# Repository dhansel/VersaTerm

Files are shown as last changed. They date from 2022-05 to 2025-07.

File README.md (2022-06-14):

# VersaTerm
A versatile DIY serial terminal.

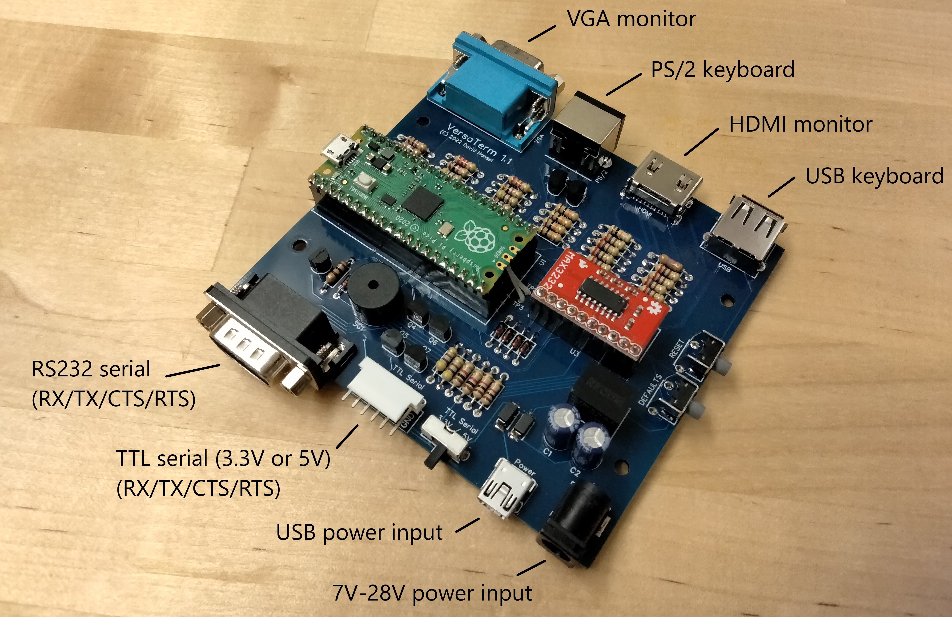
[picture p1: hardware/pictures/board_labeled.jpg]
Labeled Board

(more pictures [here](hardware/pictures/ReadMe.md))

## Highlights

- Instant-on/Instant-off - no waiting for OS to boot, no need to shut down safely
- Native HDMI and VGA video output (no conversion)
- Supports PS/2 and USB keyboards (including keyboards with integrated USB hubs)
- RS232 and TTL level serial input/output (TTL switchable between 3.3V and 5V)
- Wide range of baud rates: 50-921600 baud (presets and custom)
- Supports hardware (RTS/CTS) and software (XOn/XOff) flow control
- Can be powered via USB or 7-28V DC
- [Highly configurable](software/screenshots/settings.md), including user-uploadable fonts (bitmaps)
- Supports all [VT100 attributes](software/screenshots/vt100.md): bold/underline/blink/inverse/double width/double height
- Supports [16 ANSI colors](software/screenshots/vt100.md#ANSI-colors)
- Decent VT100 control sequence support - [passes VTTest tests](software/screenshots/vttest.md) for 80-column VT52/VT100/VT102
- [PETSCII mode](software/screenshots/petscii.md) supports PETSCII character set and control characters, PETSCII (C64) font included
- Easy to DIY - vast majority of soldering is through-hole, firmware can be uploaded via USB (no special equipment required)

### Limitations

The terminal is powered by a Raspberry Pi Pico. The Pico is a microcontroller and does not have integrated graphics
capabilities. It can however still produce video signals (see [PicoDVI](https://github.com/Wren6991/PicoDVI) 
and [PicoVGA](https://github.com/Panda381/PicoVGA)). 
Some limitations for the terminal arise from the Pico's limited processing power:

- Max 80 columns per row (no 132 column support)
- Font characters must be 8 pixels wide (original VT100 was 10 pixels), height can be 8-16 pixels
- 16 Ansi colors only (no 8-bit or 24-bit color support)
- No smooth scrolling (emulated via delayed scrolling)

## Building VersaTerm

This is not a kit but building VersaTerm should be fairly easy:

- The Gerber file to produce the PCB is available [here](https://github.com/dhansel/VersaTerm/raw/main/hardware/PCB/VersaTermGerber.zip)
- See [here](hardware/PCB/ReadMe.md) for component sourcing and assembly tips
- STL files for 3d printing an enclosure can be found [here](hardware/enclosure)
- Instructions on how to upload the firmware binary (via USB micro cable, no extra hardware needed) are [here](software/ReadMe.md)

## Using VersaTerm

### Settings menu and multiple configurations.

The settings menu can be entered by pressing the F12 keyboard key and navigated
using the cursor keys.

The "Manage Configurations" sub-menu provides 10 slots to save configurations
(e.g. if you want to use VersTerm with different computers).
- To save the current settings to the selected cofiguration slot, press "S"
- To make the selected configuration slot the startup default, press "*"
- To give the selected configuration slot a name, press "N"

You can switch between configurations via either of these methods:
- On startup or RESET, hold down the F1-F10 keyboard keys to select a configuration
- While VersaTerm is on, press CTRL and F1-F10 to load a configuration
- Press CTRL+F12 to open a quick-select menu that shows your configurations and their names

### Video output selection (HDMI/VGA)

VersaTerm can produce either VGA or HDMI output but not both at the same time. On startup, VersaTerm detects whether
a HDMI monitor is connected (via the HDMI "Hot Plug Detect" signal pin). If a HDMI monitor is detected then HDMI
output is produced, otherwise VGA. You can disable auto-detect and directly specify the output type in the "Screen"
settings menu. If your HDMI monitor is not detected at all, the HDMI output can be forced by doing the following:

- Connect a keyboard
- Hold down the RESET and DEFAULTS buttons on the side of the VersaTerm PCB
- Hold down the CTRL key on the keyboard
- Release RESET

Doing so will use default settings but disable auto-detect and instead force HDMI output. 
Once you have a monitor image you can enter settings,  fix the output type to HDMI and save 
the settings so HDMI is always used automatically.

### USB mode

The Raspberry Pi Pico has only one USB port which can function either as a USB host or device.
If the Pico is connected to another computer using the USB micro socket on the Pico board then
VersaTerm will detect that at startup and run the USB port as a device. Otherwise it assumes
that the USB port should be run as a host and allow a USB keyboard to be connected.

Do not connect the Pico to another computer **and** plug in a USB keyboard at the same time. 
Doing so won't break anything but the USB port won't function properly.

If the USB port is plugged into another computer (i.e. used as a device) then VersaTerm should
be recognized by the computer as a USB CDC (serial) device. In that case there are three operating
modes that can be selected in the USB settings menu:
- *Serial.* In this mode VersaTerm views the USB connection as a secondary serial connection. Any data received is treated just the same as data received on the main serial connection and keypresses are sent to both the main and the USB connection.
- *Feed-through.* In this mode (which is the default) VersaTerm forwards any data received on the main serial connection to USB and vice versa. This way VersaTerm can be used as a USB-to-serial converter.
- *Feed-through (terminal disabled).* Similar to the basic feed-through mode but VersaTerm won't process any input it receives from the main serial connection. This can be used to transfer (binary) data between the main serial connection and the USB serial connection without messing up the terminal display.

### Resetting the terminal

The terminal can be reset by pressing the RESET button on the side of the PCB. 

If you get yourself into a situation where VersaTerm will not work because of invalid default settings
(e.g. set to force HDMI output but you only have a VGA monitor), hold down the DEFAULTS button
(next to RESET) on the side of the PCB while pressing and releasing RESET. This will re-start
VersaTerm with the default settings.

## Screen Shots

See [here](software/screenshots/ReadMe.md) for some demonstrations of VersaTerm's capabilities

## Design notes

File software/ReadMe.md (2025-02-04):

## Uploading the VersaTerm firmware to the Raspberry Pi Pico

Uploading firmware to the Raspberry Pi Pico is easy:
- Press and hold the button on the Raspberry Pi Pico (there is only one) 
- While holding the button, connect the Raspberry Pi Pico via its micro-USB port to your computer
- Release the button
- Your computer should recognize the Pico as a storage device (like a USB stick) and mount it as a drive
- Copy the [VersaTerm.uf2](software/VersaTerm.uf2) file to the drive mounted in the previous step

## Building the VersaTerm firmware from source

### Requirements
- CMake 3.12 or later
- GCC (cross-)compiler: arm-none-eabi-gcc

### Getting and building the source

```
git clone https://github.com/dhansel/VersaTerm.git
cd VersaTerm/software/lib
git submodule update --init
cd pico-sdk/lib
git submodule update --init
cd tinyusb
git checkout 86ad6e5
cd ../../../..
mkdir build
cd build
cmake .. -DPICO_SDK_PATH=../lib/pico-sdk -DPICO_COPY_TO_RAM=1
make
```

The `git checkout 86ad6e5` command updates TinyUSB to version 0.18 instead of version 0.12
which was included with the pico-sdk version used by VersaTerm. Version 0.12 has issues
with (some) USB hubs which are resolved in 0.18.

This should create file VersaTerm/software/build/src/VersaTerm.uf2<br>
Follow the "Uploading firmware to Raspberry Pi Pico" instructions above to upload the .uf2 file to the Pico.

The instructions above will use the of pico-sdk and PicoDVI versions that were
current when I wrote and tested VersaTerm. Building from those sources should result in
the same VerTerm.uf2 file as the one in VersaTerm/software.

If you feel adventurous you can build VersaTerm with the latest versions of the libraries:
```
git clone https://github.com/dhansel/VersaTerm.git
cd VersaTerm/software/lib
git submodule update --init
cd pico-sdk/lib
git submodule update --init
git submodule update --remote --merge
cd ../..
git submodule update --remote --merge
cd ..
mkdir build
cd build
cmake .. -DPICO_SDK_PATH=../lib/pico-sdk -DPICO_COPY_TO_RAM=1
make
```

## Some solutions to compile issues

A big thank you to user [unclouded](https://github.com/un-clouded) who reported a number of compile-time 
issues and their solutions:

When it said to me:

    arm-none-eabi-gcc: fatal error: cannot read spec file 'nosys.specs': No such file or directory

I replied:

    apt install libnewlib-arm-none-eabi

And when it said:

    fatal error: cassert: No such file or directory

I retorted:

    apt install libstdc++-arm-none-eabi-dev

And then it complained that:

    /usr/lib/gcc/arm-none-eabi/12.2.1/../../../arm-none-eabi/bin/ld: cannot find -lstdc++: No such file or directory

And I spake thusly:

    apt install libstdc++-arm-none-eabi-newlib

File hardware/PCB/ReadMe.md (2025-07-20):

# Component Ordering

I sourced most of the parts from DigiKey. The [VersaTermBOM.csv](VersaTermBOM.csv) file in this folder includes all the parts and their part numbers.
You can also click the link below to automatically create a shopping cart at DigiKey that contains most of the parts:<BR>
https://www.digikey.com/short/d0qw14h1

The the following necessary parts are currently not available at DigiKey and have to be ordered separately:
  - Raspberry Pi Pico: not sold at DigiKey, available at [AdaFruit](https://www.adafruit.com/product/4883), [SparkFun](https://www.sparkfun.com/products/17829), Ebay and others
  - 2N7000 MOSFET (need 7): currently (May 2022) on backorder at DigiKey. Available on EBay from various sellers.

If you want to use the provided [3d-printable enclosure](../enclosure), you will need four machine screws #4-40 with length 22mm (7/8") below the head and matching
#4-40 nuts. DigiKey part #335-1089-ND and #36-9600-ND will fit.
  
# Assembly tips
  
The vast majority of solder points are through-hole and easy to solder, except for the following:
  - Diodes D1 and D2 are surface-mount devices but the diodes themselves are fairly large. I have no SMD soldering experience and had no problem soldering them.
  - The Raspberry Pi Pico does not route the USB data signals to its pin headers. However, there are two test points (TP2 and TP3) on the bottom of the Pi Pico 
  on which the USB data signals can be accessed. Solder in a short wire from TP2 on the Pi Pico board to TP2 on the VersaTerm PCB. Same for TP3.
  <div align="center">
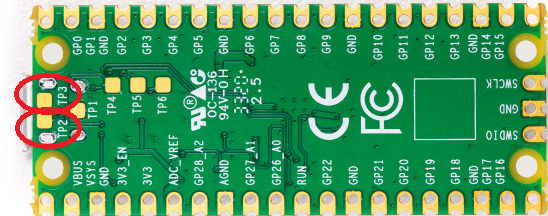
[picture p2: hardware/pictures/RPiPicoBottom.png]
  
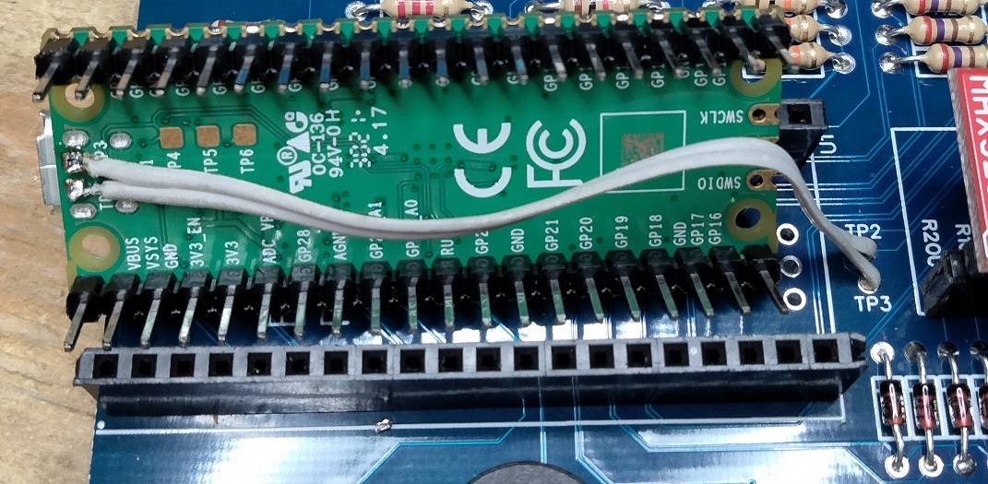
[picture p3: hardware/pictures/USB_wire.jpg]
  
  </div>
  
  - While the HDMI connector is through-hole, its pins are very closely spaced. I definitely recommend using a multimeter to check there are no solder bridges 
  between the pins after soldering.
  
  Other tips:
  - For the Raspberry Pi Pico, solder female header pins onto the PCB and then male header pins to the Pi Pico. That will make it easier to debug issues later 
  or to replace the Pico if that becomes necessary.
  - I also used male/female headers to connect the Max3232
  - When soldering the male Molex connector for the TTL serial connection to the board, do not stick it into the board as far as it will go, otherwise the 
  female connector will not fit afterwards. I recommend soldering the male connector while plugged into the female one, that way there is definitely enough space.

# Component Placement

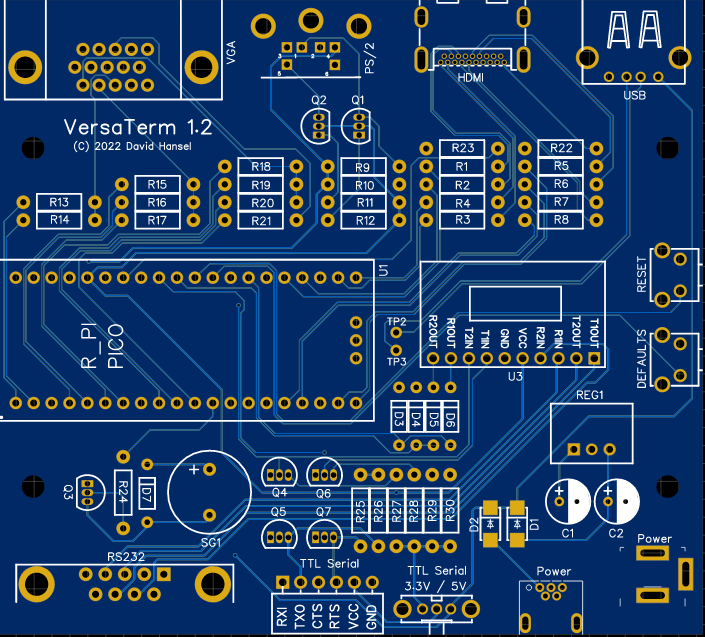
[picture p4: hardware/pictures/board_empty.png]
Empty Board

  
For supplier and manufacturer part numbers, see [VersaTermBOM.csv](VersaTermBOM.csv)

Designator	|  Component
------------|-------------
R21,R24	| Resistor 100 Ohm
R1,R2,R3,R4,R5,R6,R7,R8	| Resistor 270 Ohm
R14	| Resistor 390 Ohm
R17,R20,R25,R26	| Resistor 470 Ohm
R13,R16,R19,R27,R28	| Resistor 1k
R29,R30	| Resistor 1k or 10k (see note below)
R15,R18	| Resistor 2k2
R22	| Resistor 4.7k
R9,R10,R11,R12,R23	| Resistor 10k Ohm
D1,D2	| Diode SMT Schottky
D3,D4,D5,D6,D7 | Diode Axial 1N4148
Q1,Q2,Q3,Q4,Q5,Q6,Q7 | MOSFET 2N7000
C1,C2 | Capacitor 10uF
3.3V / 5V	| Switch
RESET,DEFAULTS | Button
REG1	| Recom 5V Regulator
SG1	| Buzzer
Power	| Barrel Connector
Power	| USB-B Mini Connector
VGA	| DB15 Connector
PS/2	| PS/2 Connector
HDMI	| HDMI Connector
USB	| USB-A Connector
RS232	| DB9 Connector
TTL Serial	| Molex Connector Male
U1	| Raspberry Pi Pico
U3	| MAX3232 board

**Note:** Some users have [reported](https://github.com/dhansel/VersaTerm/issues/16) issues with VersaTerm receiving data, which was caused by the R29/R30 1k pull-up resistors being too strong. 
If you experience issues receiving then I recommend switching these to 10k.

# Finished PCB
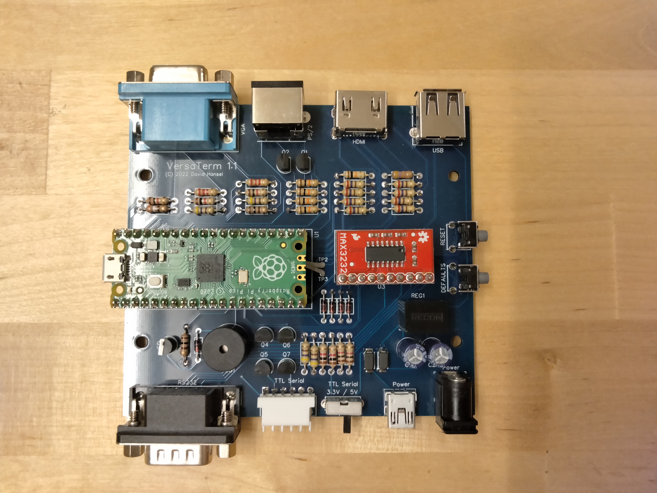
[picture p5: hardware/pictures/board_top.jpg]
board_top


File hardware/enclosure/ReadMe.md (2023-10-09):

The two halves of the encosure are held together using four machine screws #4-40 with 
length 22mm (7/8") below the head and matching #4-40 nuts. For example, DigiKey 
part #[335-1089-ND](https://www.digikey.com/en/products/detail/apm-hexseal/R4-40X7-8-2701/1159352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)
and #[36-9600-ND](https://www.digikey.com/en/products/detail/keystone-electronics/9600/2746248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) will fit.

If you would like to use M3 bolts instead, take a look at [this variation of the enclosure](DigicoolThings).

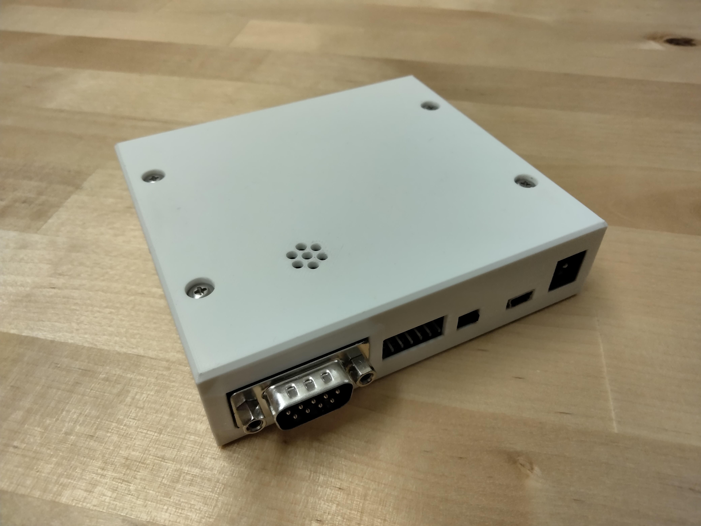
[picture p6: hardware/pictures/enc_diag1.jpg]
enclosure


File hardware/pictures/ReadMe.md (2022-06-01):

# PCB pictures

board_top
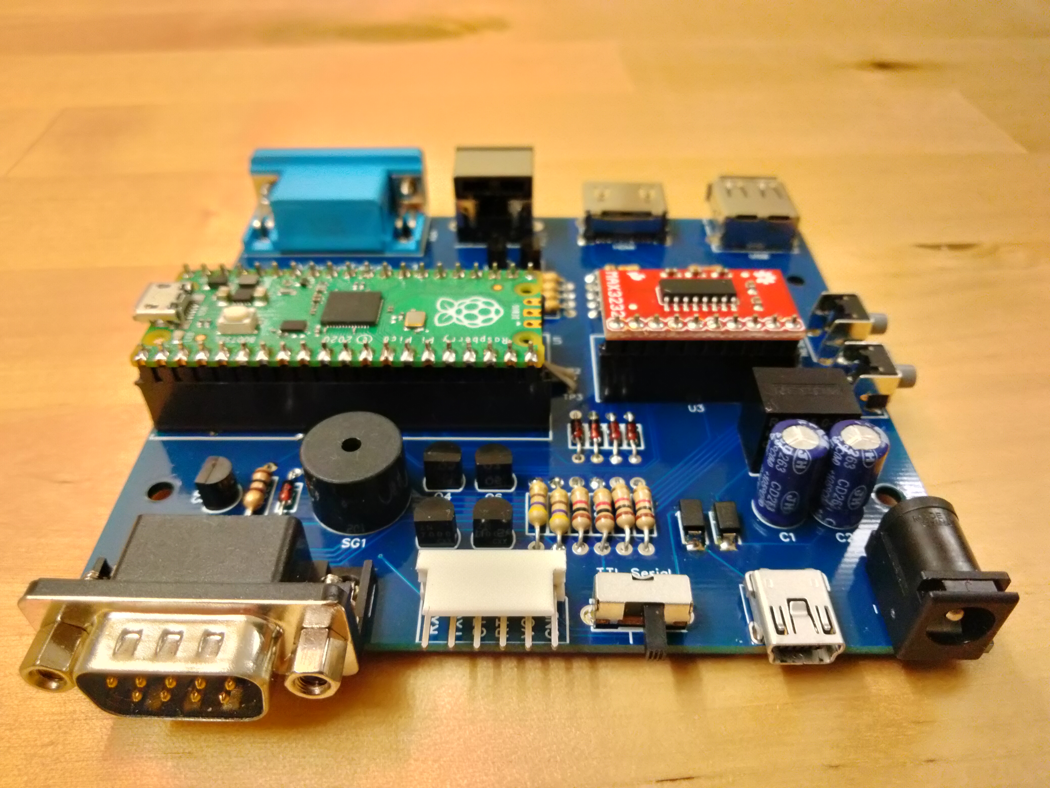
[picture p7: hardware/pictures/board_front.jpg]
board_front

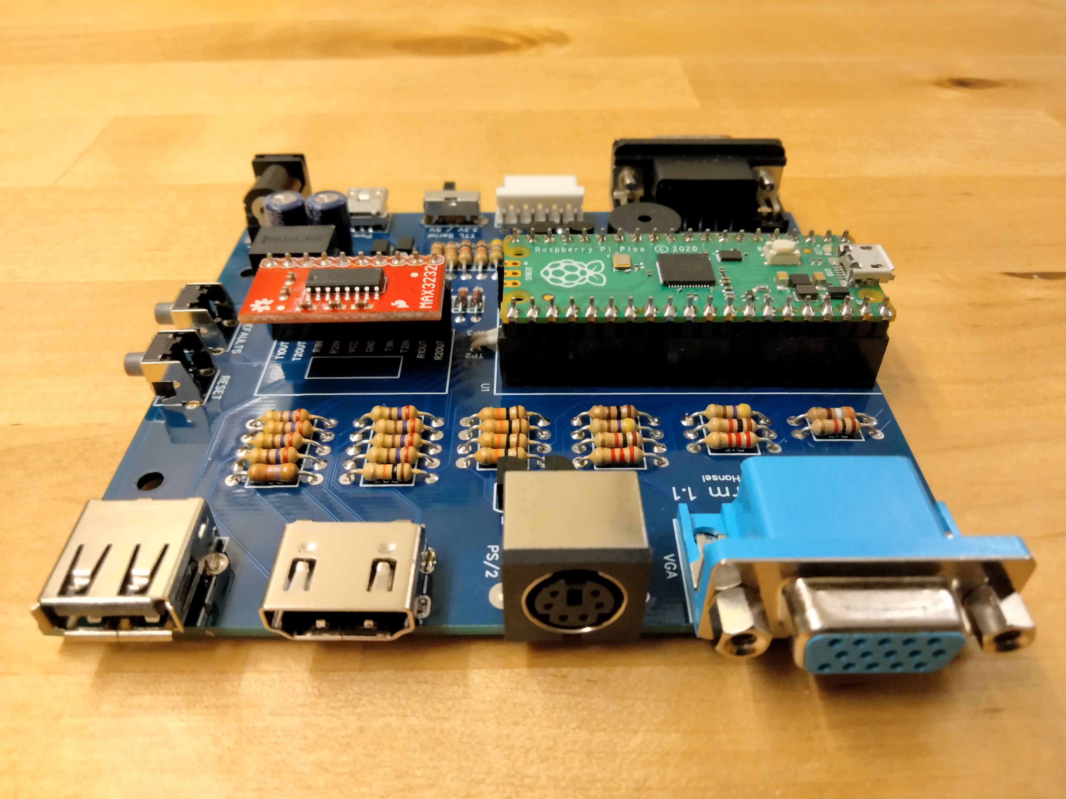
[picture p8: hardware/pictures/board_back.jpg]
board_back

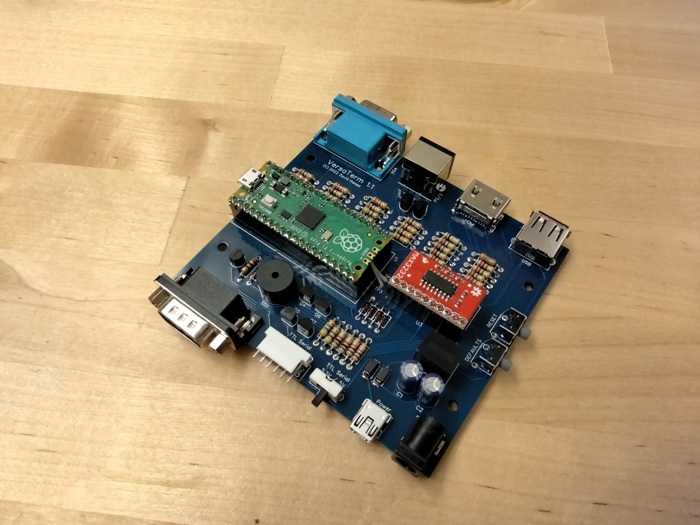
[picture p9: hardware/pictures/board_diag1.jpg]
board_diag1


# Enclosure pictures

enc_diag1
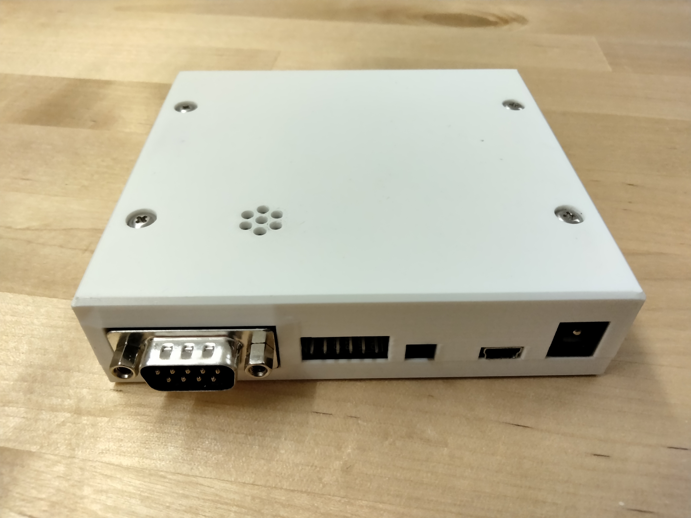
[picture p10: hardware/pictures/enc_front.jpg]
enc_front

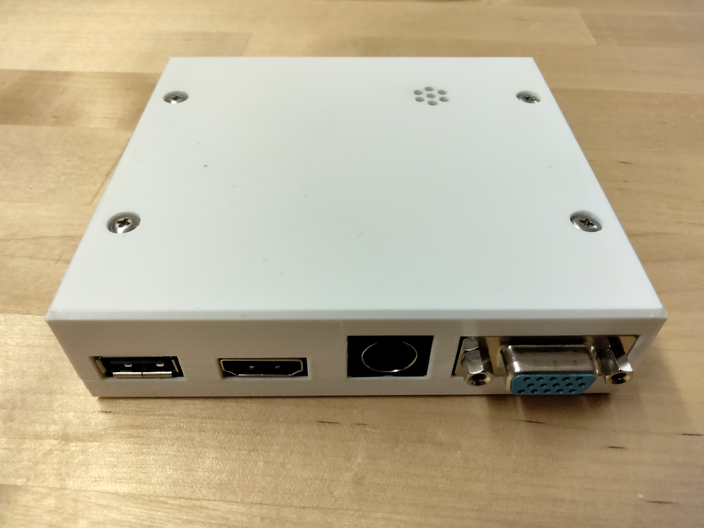
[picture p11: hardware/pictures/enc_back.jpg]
enc_back

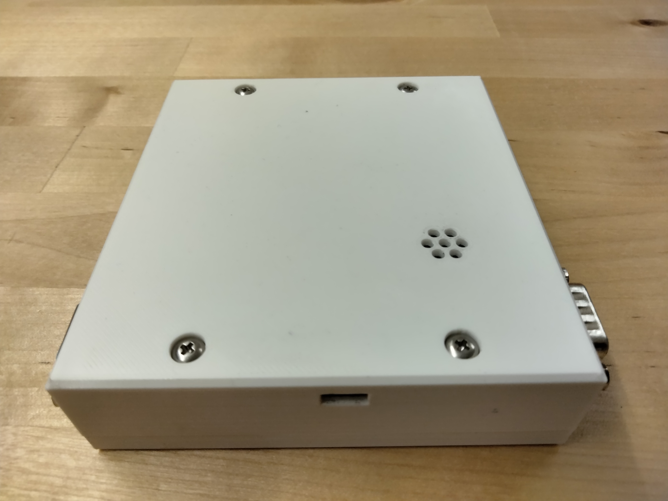
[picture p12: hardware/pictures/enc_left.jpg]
enc_left

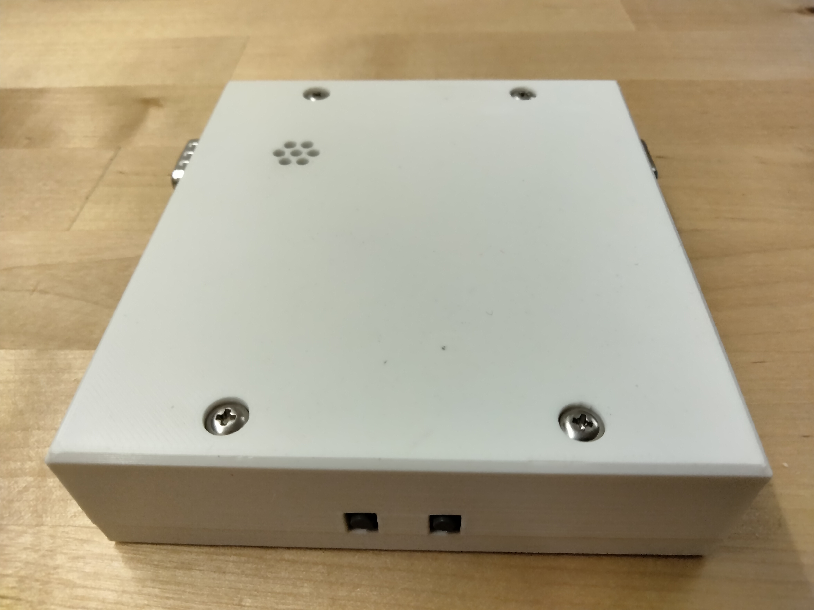
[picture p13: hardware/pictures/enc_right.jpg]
enc_right


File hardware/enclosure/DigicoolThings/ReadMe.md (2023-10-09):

This is a variation on my original enclosure, provided by Greg at [DigicoolThings](https://digicoolthings.com):

  - Bolt holes adjusted to take M3 Bolts (3.2mm), as more readily available to everyone in the metric world. 
  - Nut retainer holes adjusted for M3 Nuts (the imperial nut retainer holes were too big for M3 nuts).
  - Embeded Legends with the product name and the connector names added in 2 colors (for Bambu Lab AMS printing).

The 3d printer files for this version are available on MakerWorld:
https://makerworld.com/en/models/33128#profileId-29923

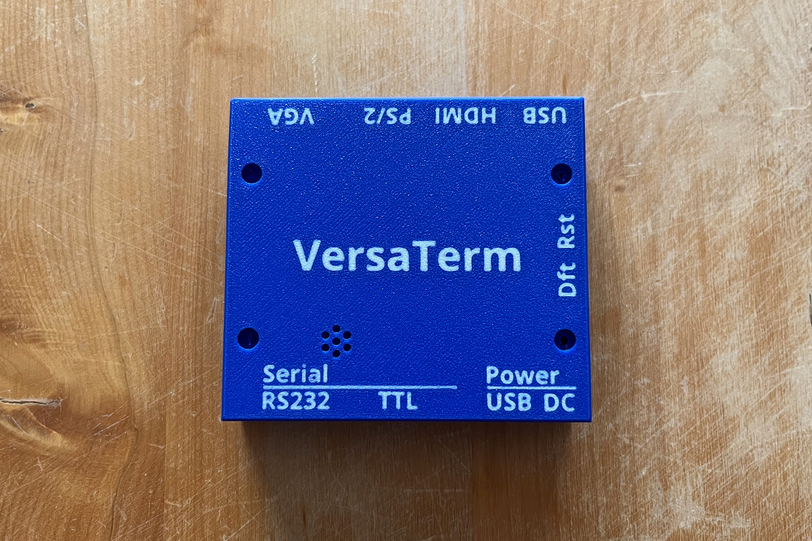
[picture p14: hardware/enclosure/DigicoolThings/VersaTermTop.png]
enclosure


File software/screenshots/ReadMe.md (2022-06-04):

# VT100/ASCII graphics

[Click here for more VT100 graphics screen shots](vt100.md)
<div align="center">
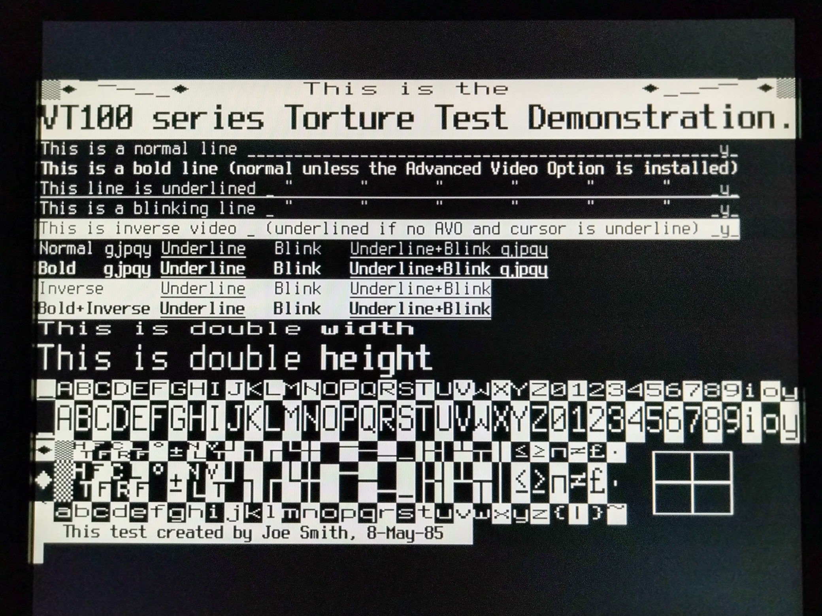
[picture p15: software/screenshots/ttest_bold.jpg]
More screenshots
  
</div>

# VTTest

[VTTest](https://invisible-island.net/vttest) is a test suite for VT100 compatibility.<br>
[Click here for more VTTest screen shots](vttest.md)
<div align="center">
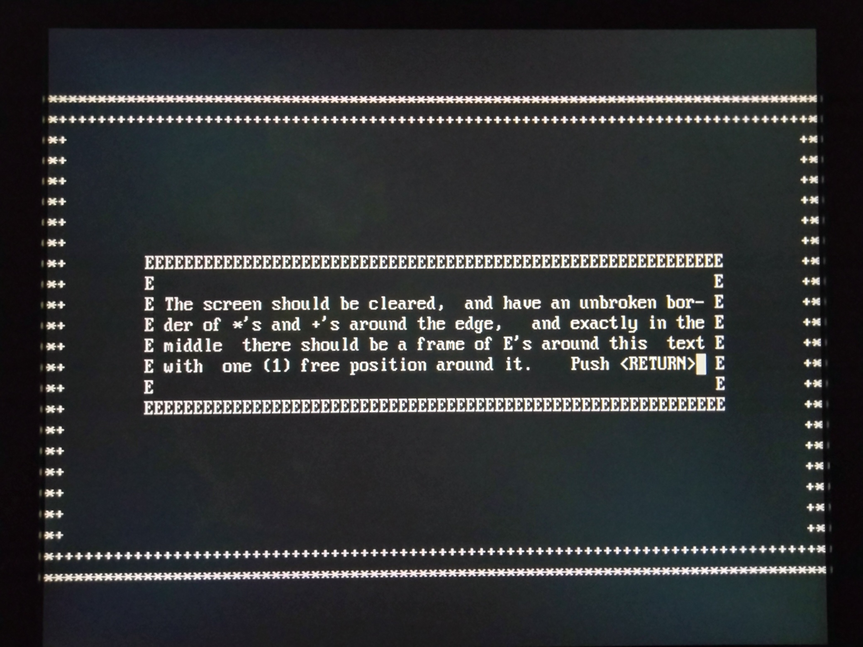
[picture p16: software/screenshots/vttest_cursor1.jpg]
More screenshots
  
</div>

# PETSCII graphics

[Click here for more PETSCII graphics screen shots](petscii.md)
<div align="center">
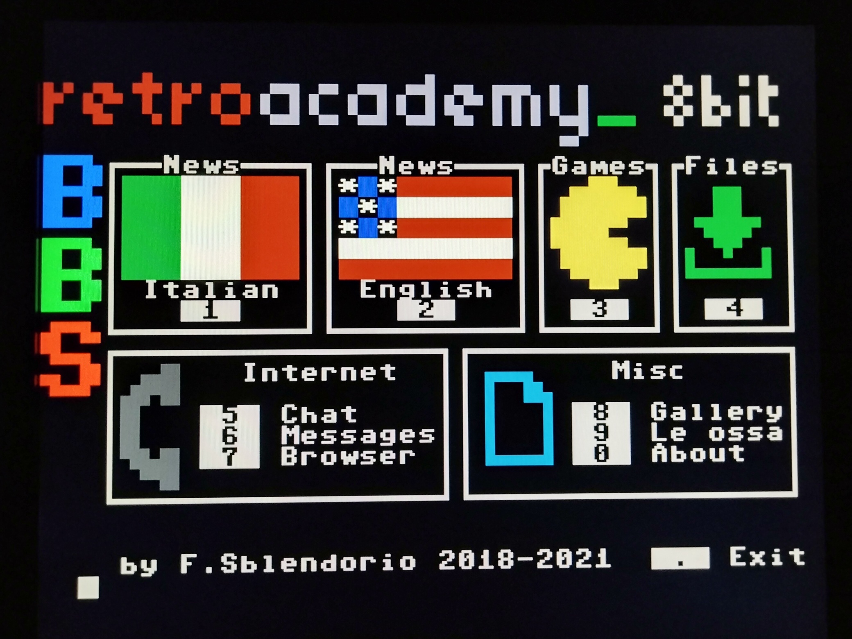
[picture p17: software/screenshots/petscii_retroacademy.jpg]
More screenshots
  
</div>

# Settings menu

[Click here for more settings screen shots](settings.md)
<div align="center">
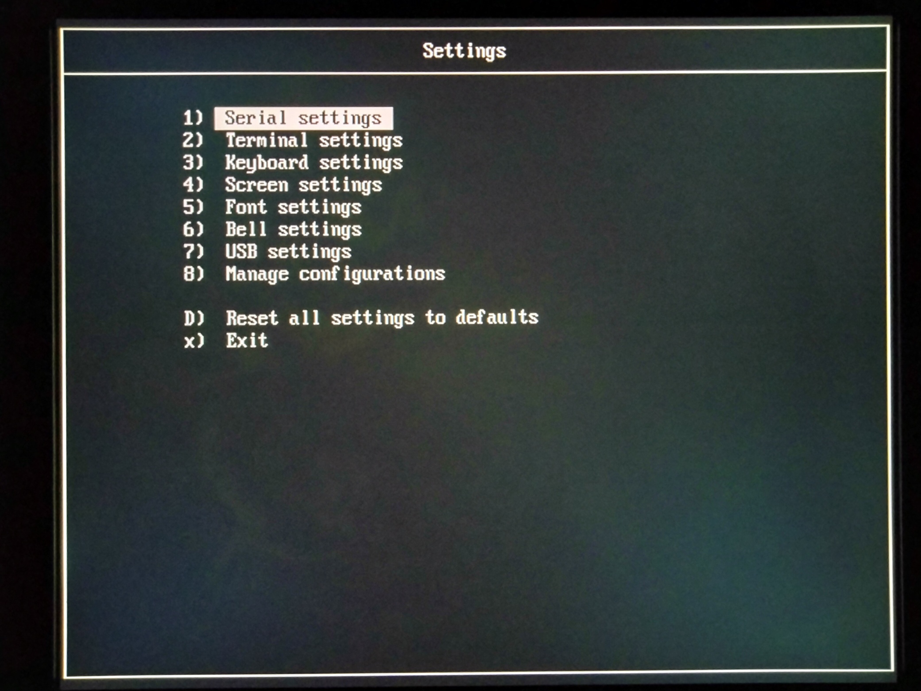
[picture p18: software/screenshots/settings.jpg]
More screenshots
  
</div>

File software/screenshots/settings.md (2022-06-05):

# Settings menu

settings
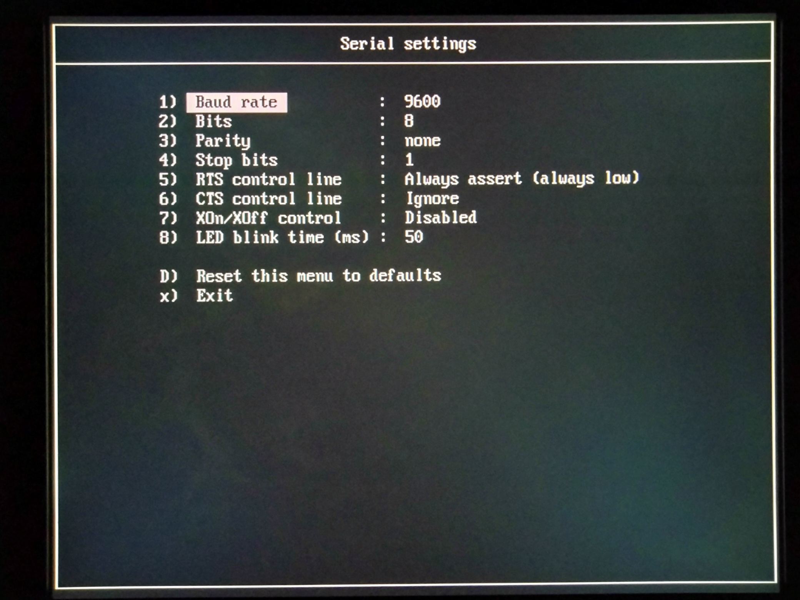
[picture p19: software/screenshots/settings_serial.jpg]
settings_serial

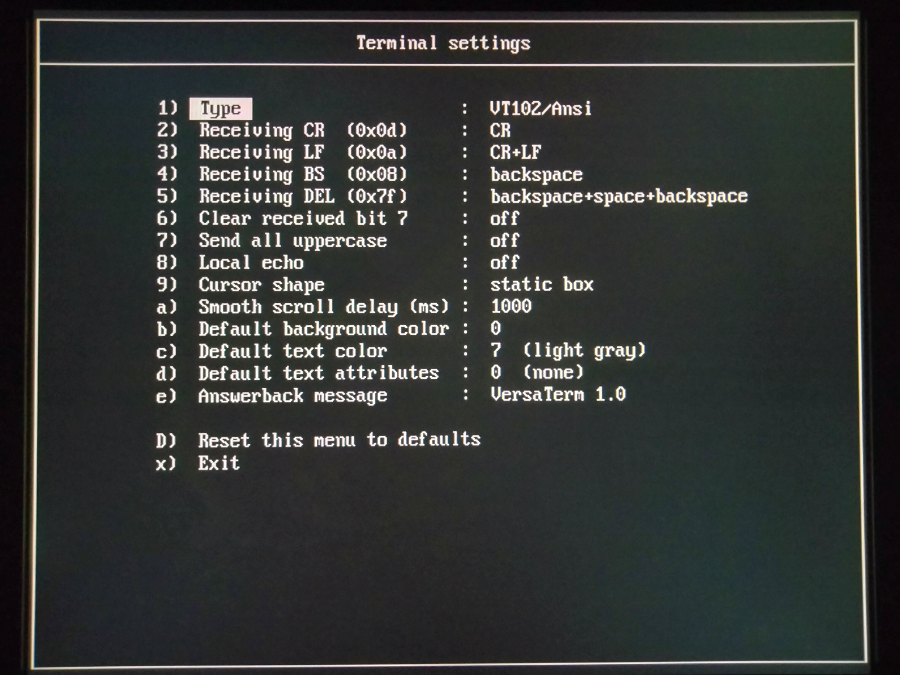
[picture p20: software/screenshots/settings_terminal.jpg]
settings_terminal

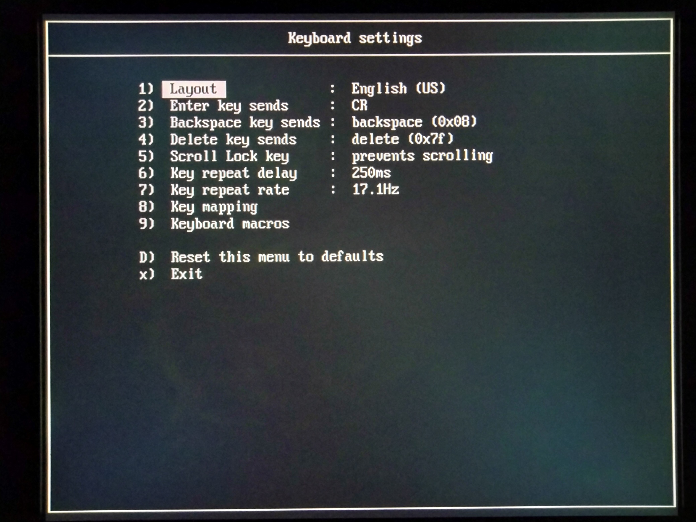
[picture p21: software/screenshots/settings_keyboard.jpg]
settings_keyboard

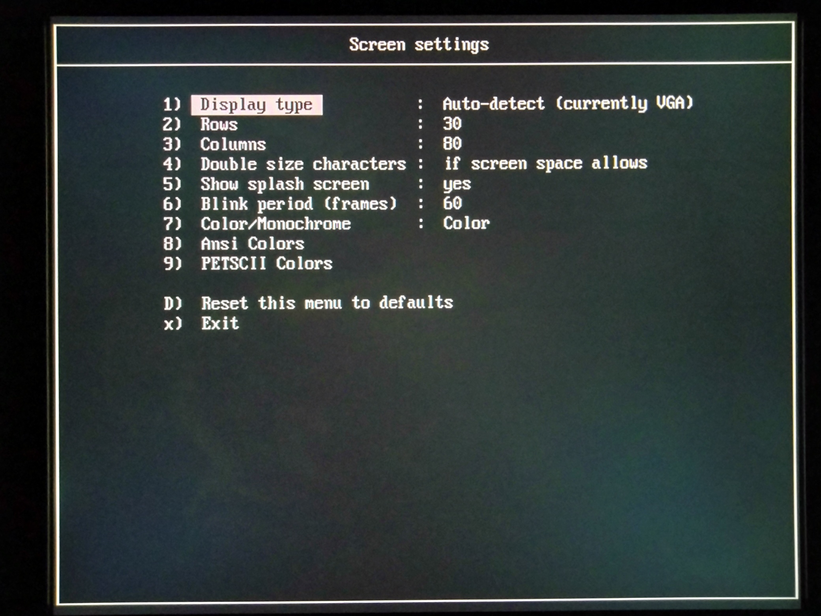
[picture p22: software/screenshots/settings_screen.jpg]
settings_screen

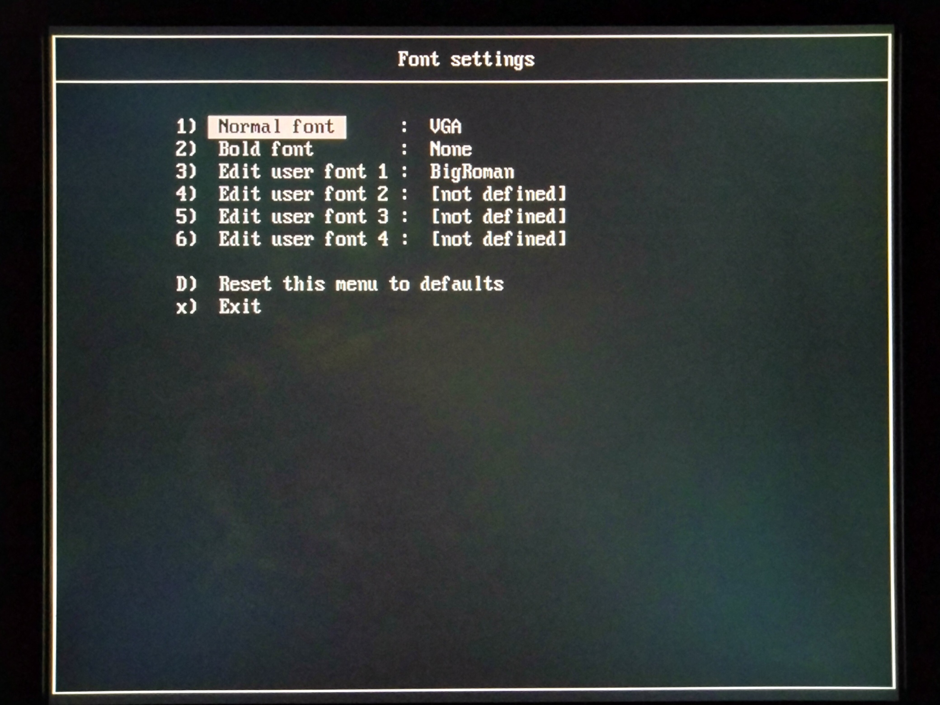
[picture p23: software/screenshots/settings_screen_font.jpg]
settings_screen_font

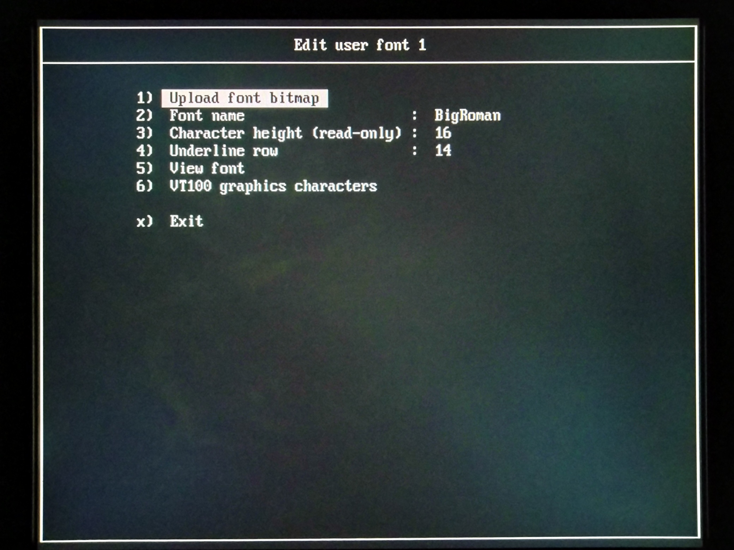
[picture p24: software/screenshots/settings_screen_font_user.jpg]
settings_screen_font_user

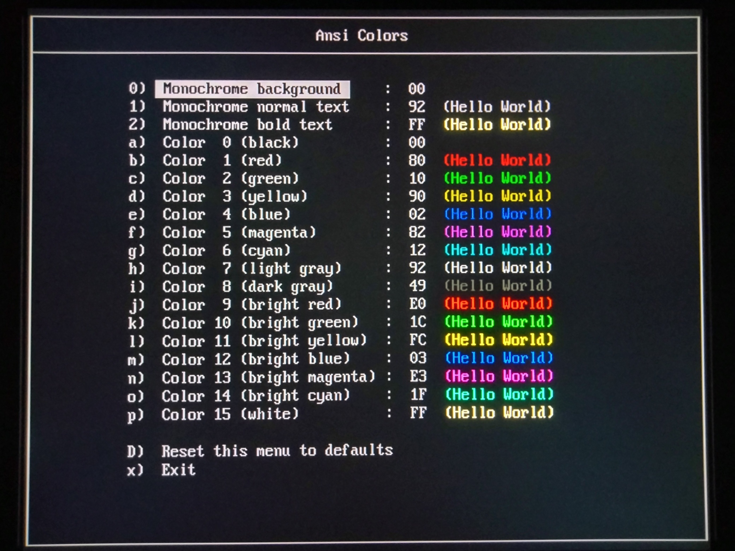
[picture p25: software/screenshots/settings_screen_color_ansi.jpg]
settings_screen_color_ansi

settings_screen_color_petscii
settings_bell
settings_usb
settings_configs

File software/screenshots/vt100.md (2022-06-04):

# VT100 / ASCII / ANSI graphics

### VT100 Torture test (using regular and bold font)

Source: http://artscene.textfiles.com/vt100 (torturet.vt)<br>
Font: Terminus / Terminus bold<br>
Click [here](https://youtu.be/B1N31KZlwjg) to see a video recording of this test.
<div align="center">
  <a href="https://youtu.be/B1N31KZlwjg">Watch the Video</a>
</div>

### VT100 Torture test (no bold font selected - using color instead)

Source: http://artscene.textfiles.com/vt100 (torturet.vt)<br>
Font: VGA / no bold font, using bright colors for bold characters<br>
Click [here](https://youtu.be/LtPrxeNTNgQ) to see a video recording of this test.
<div align="center">
  <a href="https://youtu.be/LtPrxeNTNgQ">Watch the Video</a>
</div>

### VT100 "Beer" animation

Source: http://artscene.textfiles.com/vt100 (newbeer.vt)<br>
Click [here](https://youtu.be/AVb2DMGUi1M) to see a video recording of this test.
<div align="center">
  <a href="https://youtu.be/AVb2DMGUi1M">Watch the Video</a>
</div>

### ANSI colors

ansi_colors

### ANSI graphics

Source: http://www.roysac.com/roy_ansishow.html#1
ansi_art1
ansi_art1

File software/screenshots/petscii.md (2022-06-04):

# PETSCII

petscii_retroacademy
petscii_art1
petscii_art2
petscii_art3

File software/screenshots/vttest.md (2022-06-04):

# VTTest

[VTTest](https://invisible-island.net/vttest) is a test suite for VT100 compatibility.

vttest

## Test of cursor movements

vttest_cursor1
vttest_cursor2
vttest_cursor3
vttest_cursor4

# Test of screen features

vttest_screen1
vttest_screen2
vttest_screen3
vttest_screen4
vttest_screen5
vttest_screen6
vttest_screen7
vttest_screen8
vttest_screen9

# Test of character sets

vttest_charset1

# Test of double-sized characters

vttest_double1
vttest_double2
vttest_double3
vttest_double4

# Test of VT52 mode

Note: VersaTerm currently does not support the VT52 special graphics characters.

vttest_vt52_1
vttest_vt52_2
vttest_vt52_3

# Test of VT102 features (Insert/Delete)

vttest_insdel1
vttest_insdel2
vttest_insdel3
vttest_insdel4
vttest_insdel5
vttest_insdel6
vttest_insdel7

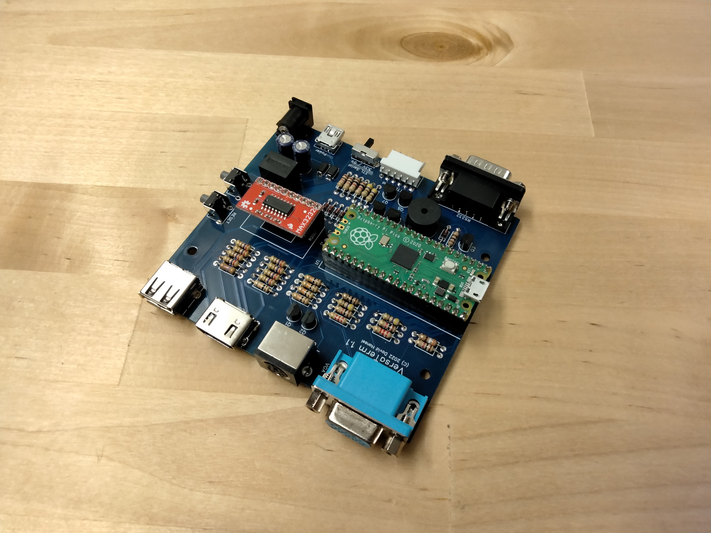
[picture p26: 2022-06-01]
hardware/pictures/board_diag2.jpg

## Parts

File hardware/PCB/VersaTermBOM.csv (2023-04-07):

Designator | Component | Quantity | Supplier | Supplier Part | Manufacturer | Manufacturer Part
R21,R24 | Resistor 100 Ohm | 2 | Digi-Key | CF14JT100RCT-ND | Stackpole Electronics Inc | CF14JT100R
R1,R2,R3,R4,R5,R6,R7,R8 | Resistor 270 Ohm | 8 | Digi-Key | CF14JT270RCT-ND | Stackpole Electronics Inc | CF14JT270R
R14 | Resistor 390 Ohm | 1 | Digi-Key | CF14JT390RCT-ND | Stackpole Electronics Inc | CF14JT390R
R17,R20,R25,R26 | Resistor 470 Ohm | 4 | Digi-Key | CF14JT470RCT-ND | Stackpole Electronics Inc | CF14JT470R
R13,R16,R19,R27,R28,R29,R30 | Resistor 1k | 7 | Digi-Key | CF14JT1K00CT-ND | Stackpole Electronics Inc | CF14JT1K00
R15,R18 | Resistor 2k2 | 2 | Digi-Key | CF14JT2K20CT-ND | Stackpole Electronics Inc | CF14JT2K20
R22 | Resistor 4.7k | 1 | Digi-Key | CF14JT4K70CT-ND | Stackpole Electronics Inc | CF14JT4K70
R9,R10,R11,R12,R23 | Resistor 10k | 5 | Digi-Key | CF14JT10K0CT-ND | Stackpole Electronics Inc | CF14JT10K0
D1,D2 | Diode SMT Schottky | 2 | Digi-Key | 641-1762-1-ND | Comchip Technology | CDBA140SL-HF
D3,D4,D5,D6,D7 | Diode Axial 1N4148 | 5 | Digi-Key | 1N4148FS-ND | Onsemi | 1N4148
Q1,Q2,Q3,Q4,Q5,Q6,Q7 | MOSFET 2N7000 | 7 | Digi-Key | 2N7000FS-ND | Onsemi | 2N7000
C1,C2 | Capacitor 10uF | 2 | Digi-Key | 399-18279-1-ND | KEMET | ESS106M063AE2EA
3.3V / 5V | Switch | 1 | Digi-Key | EG1906-ND | E-Switch | EG1213
RESET,DEFAULTS | Button | 2 | Digi-Key | CKN9120-ND | C&K | PTS645VH58-2 LFS
REG1 | Recom 5V Regulator | 1 | Digi-Key | 945-2201-ND | Recom Power | R-78E5.0-1.0
SG1 | Buzzer | 1 | Digi-Key | 668-1470-ND | PUI Audio, Inc. | AT-1224-TWT-5V-2-R
Power | Barrel Connector | 1 | Digi-Key | A107788-ND | TE Connectivity AMP Connectors | 1734510-1
Power | USB-B Mini Connector | 1 | Digi-Key | CP-002A-ND | CUI Devices | PJ-002A
VGA | DB15 Connector | 1 | Digi-Key | 2092-K66X-E15S-N-VESA-ND | Kycon, Inc. | K66X-E15S-N-VESA
PS/2 | PS/2 Connector | 1 | Digi-Key | CP-2260-ND | CUI Devices | MD-60SM
HDMI | HDMI Connector | 1 | Digi-Key | 1175-1700-ND | CNC Tech | 2000-1-1-20-00-BK
USB | USB-A Connector | 1 | Digi-Key | ED2989-ND | On Shore Technology Inc. | USB-A1HSW6
RS232 | DB9 Connector | 1 | Digi-Key | AE10968-ND | Assmann WSW Components | A-DS 09 A/KG-T2S
TTL Serial | Molex Connector Male | 1 | Digi-Key | A1928-ND | TE Connectivity AMP Connectors | 640457-6
U1 | Raspberry Pi Pico | 1 | AdaFruit | 4883 | Raspberry Pi | SC0915
U3 | MAX3232 board | 1 | Digi-Key | 1568-1193-ND | SparkFun | BOB-11189
 | Header Male 40 Pin | 2 | Digi-Key | 732-5334-ND | Würth Elektronik | 61304011121
 | Header Female 40 Pin | 2 | Digi-Key | HDR100IMP40F-G-V-TH-ND | Chip Quik Inc. | HDR100IMP40F-G-V-TH
 | D-Sub Jackscrew | 2 | Digi-Key | 2057-JS-02-ND | Adam Tech | JS-02
 | Molex Housing Female | 4 | Digi-Key | A99617-ND | TE Connectivity AMP Connectors | 1375820-6
 | Molex Crimp Pins | 25 | Digi-Key | A100453CT-ND | TE Connectivity AMP Connectors | 1375819-1

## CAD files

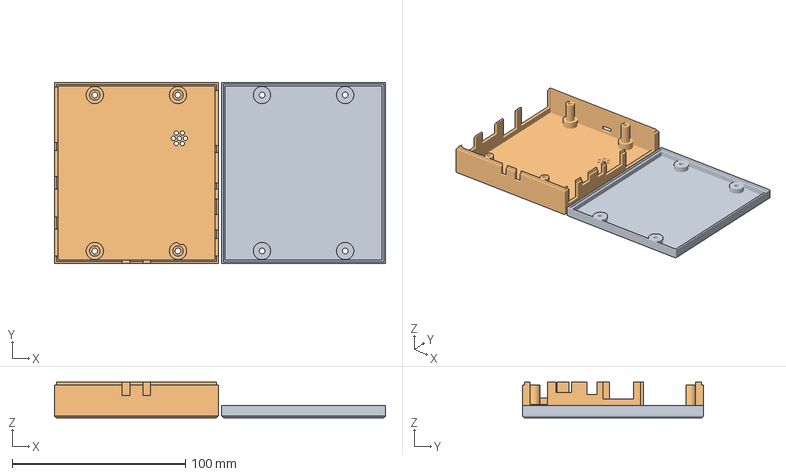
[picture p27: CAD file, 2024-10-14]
hardware/enclosure/DigicoolThings/VersaTerm.3mf
191.0 x 104.5 x 20.6 mm
VersaTermTop v8.stl

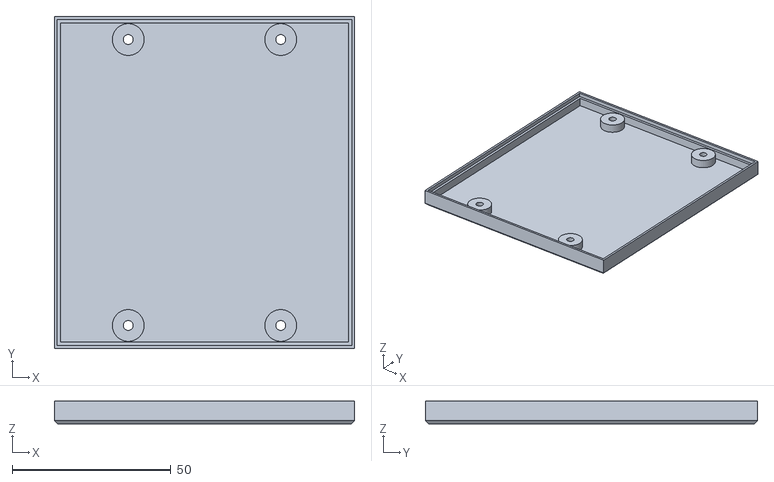
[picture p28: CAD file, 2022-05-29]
hardware/enclosure/VersaTermBottom.stl
94.5 x 104.5 x 7.10

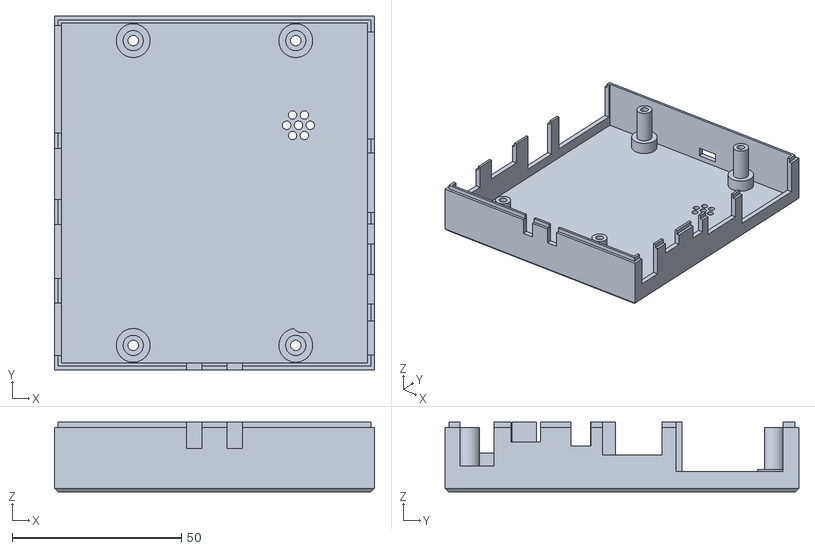
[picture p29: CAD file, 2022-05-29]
hardware/enclosure/VersaTermTop.stl
94.5 x 104.5 x 20.6

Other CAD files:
hardware/enclosure/DigicoolThings/VersaTermBottom.f3d
hardware/enclosure/DigicoolThings/VersaTermTop.f3d
hardware/enclosure/VersaTermBottom.f3d
hardware/enclosure/VersaTermTop.f3d

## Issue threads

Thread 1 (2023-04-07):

Component Correction from Digikey

okwatts, 2023-04-07:
The component number for the Max3232 board from Digikey is 1568-1193-ND not 1568-1208-ND

dhansel, 2023-04-07:
Thanks for the correction! I've updated the BOM.

Closed 2023-04-07.

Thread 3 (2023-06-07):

Question re trapping of function keys

okwatts, 2023-06-07:
HI I have built 2 of these and quite like them for my retro hobby. I recently ran across a situation using a screen editor that uses the function keys to save and exit from it. This works under putty and Teraterm but doesn't under versaterm. Is this related to checking for F12 and are all F keys affected?

dhansel, 2023-06-08:
As far as I know the VT100/VT102 standard did not include mappings for function keys, which is why VersaTerm does not include them either. TeraTerm and Putty also support other standards which I assume include the function keys.

If you know the ASCII sequence your editor expects for the function keys then you can use the keyboard macro function in VersaTerm to define the proper sequence:
1) press F11 (you will hear a single beep)
2) press the function key you want to re-define (best stick to F1-F10 since F11 and F12 have meaning in VersaTerm itself)
3) press the keyboard key sequence you want the function key to send
4) press F11 again (a double beep will indicate that the macro has been recorded)

Now every time you press the function key, VersaTerm will send that sequence. When you save your configuration the keyboard macros will be included.

Note that during step 3 you can send _any_ ASCII code by pressing and holding the left ALT key and then typing the three-digit (decimal) ASCII code on the _number keypad_ on your keyboard. For example: [hold down LEFT-ALT] 0 6 5 [release LEFT-ALT] will produce an upper-case A. This works at any time, not just when defining macros.

okwatts, 2023-06-08:
Thanks for the quick response I will check this out and see. I have the
source for the editor so that should help.

On Thu, Jun 8, 2023 at 5:22 AM David Hansel ***@***.***>
wrote:

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

CygnusTM, 2023-07-15:
I just discovered this project and wanted to chime in here as a relative old timer.

> As far as I know the VT100/VT102 standard did not include mappings for function keys, which is why VersaTerm does not include them either.

The original VT100-series terminals had four function keys, PF1-PF4. As far as I recall, everything I've used with VT100 emulation (going back to the 80s) maps at least those four.

dhansel, 2023-07-16:
Thanks for the info! I had another look at the manual and don't understand how I missed
the PF1-PF4 keys before. To map F1/F2/F3/F4 to the corresponding sequences (ESC O P/Q/R/S) using macros:
1. For F1 press: F11 F1 ESC O P F11
2. For F2 press: F11 F2 ESC O Q F11
3. For F3 press: F11 F3 ESC O R F11
4. For F4 press: F11 F4 ESC O S F11

It shouldn't be hard to add the mapping natively. I'm currently away from home but will
take a look when I get back.

dhansel, 2023-09-16:
I finally got around to implementing support for the PF1-PF4 function keys on the VT100 keyboard (using F1-F4 on regular keyboards. In the latest version the correct sequences for those keys are now produced.

Closed 2023-09-25.

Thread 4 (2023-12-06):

can't the code to compile

soviet9922, 2023-12-06:
Hi trying to get the last source + tinyusb updates compiled but can't get it to work get the error in screenshot.

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

Maybe you can point out the problem or even better you may have an updated release and can upload it to this git ?.

Thanks !.

:)

javavi, 2023-12-07:
I'm just adapting this project to a different scheme.
[image: Murmulator-VersaTerm.JPG]
I assembled the code according to the instructions in the Windows
environment.
The original project code is here:
https://github.com/dhansel/VersaTerm

ср, 6 дек. 2023 г. в 02:38, soviet9922 ***@***.***>:

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

Commander1024, 2023-12-19:
I have the exact same issue.

That is after merging pico-sdk (and picodvi) origin/master into the workingdir (of the submodules), because the currently selected picosdk will otherwise fail even earlier.

Honestly I am not a genius in C in general and with rpi pico development specifically.

I did try various path modifications in software/src/keyboard.c trying to point it to: ../lib/pico-sdk/lib/tinyusb/hw/bsp/rp2040/board.h though, but no avail.

I figure the 3 months old binary .uf2 (resp. its corresponding pico-sdk) build might be fresh enough to support keyboards with USB hubs by now, but still... ;-)

dhansel, 2023-12-21:
Sorry work has been very busy the past few weeks. I'm hoping to find some time next week to take a look at this.

The .uf2 file in the distribution should support keyboards with USB hubs though.

dhansel, 2023-12-28:
Turns out the #include directives that the compiler complained about were not needed (even for the older version of tinyusb).
I have removed them in the git repository, so if you update your code you should be able to compile using the latest versions
of pico-sdk, tinyusb and PicoDVI.

@Commander1024 I can't reproduce any compile issues with the currently linked versions of the libraries.
Do you have any more details on what errors you are getting?

Commander1024, 2023-12-28:
Actually it works for me now, too with updated main. Although I had to include stdint.h in xmodem.c, which it was complaining

```
diff --git a/software/src/xmodem.c b/software/src/xmodem.c
index 6c26654..183c0a8 100644
--- a/software/src/xmodem.c
+++ b/software/src/xmodem.c
@@ -17,6 +17,7 @@
 // Inc., 51 Franklin Street, Fifth Floor, Boston, MA 02110-1301  USA
 // -----------------------------------------------------------------------------

+#include <stdint.h>
 #include <stdio.h>
 #include <string.h>
 #include <stdlib.h>
```

dhansel, 2023-12-28:
Thanks, I added the #include

Closed 2024-01-01.

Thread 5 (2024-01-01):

Circuit schematic (pdf) doesn't render

n6502, 2024-01-01:
Hi David
Trying to view the VersaTerm schematic (pdf) within github doesn't render. Downloading to my PC, trying to open, my pdf reader reports file as invalid.
Thanks
Nigel

dhansel, 2024-01-01:
Hi Nigel,

I just tried this here and it renders just fine for me, in GitHub as well as after downloading:
https://github.com/dhansel/VersaTerm/blob/main/hardware/PCB/VersaTermSchematic.pdf

Can you try again - maybe it was a temporary glitch in GitHub?

David

n6502, 2024-01-01:
Hi David

Many thanks for checking this out, and for your very prompt reply.
I've successfully viewed the embedded pdf in another (chrome) browser on a tablet, so the issue appears related to my PC (running Opera).
Weirdly, I can now download the pdf to my PC (using Opera) and open it in my pdf reader, but checking other projects with pdf files, it seems I can't view embed pdfs. Hey ho - technology...
This issue can be closed - apologies for taking your time.
Regards
Nigel

dhansel, 2024-01-01:
No worries, glad you figured it out!

Closed 2024-01-01.

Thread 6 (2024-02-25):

The requirements to build from source could use a couple more steps

un-clouded, 2024-02-25:
When it said to me:

    arm-none-eabi-gcc: fatal error: cannot read spec file 'nosys.specs': No such file or directory

I replied:

    apt install libnewlib-arm-none-eabi

And when it said:

    fatal error: cassert: No such file or directory

I retorted:

    apt install libstdc++-arm-none-eabi-dev

And then it complained that:

    /usr/lib/gcc/arm-none-eabi/12.2.1/../../../arm-none-eabi/bin/ld: cannot find -lstdc++: No such file or directory

And I spake thusly:

    apt install libstdc++-arm-none-eabi-newlib

These are already in `lib/pico-sdk/README.md`, but it'd be super handy to have them at the top level too.  Thanks heaps!

dhansel, 2024-03-03:
Thanks for the report! I've added your solutions to the Readme file!

Closed 2024-05-11.

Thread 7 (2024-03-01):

Feature request / discussion: Additional (font) characters

Commander1024, 2024-03-01:
Ohai,

I built a VersaTerm and it work totally fine. But aside of retro computers (following the VT102 standard), I do like using it on (modern) Linux/BSD boxes as well. It's fantastic that it does support ridiculous high baud rates and ANSI color support fills my heart with love, too.

I have just a minor thing that bothers me a bit, and that is the German umlauts (or other language-specific chars and maybe a few (?) pseudo graphic UTF-8 characters). Those are printed as escape sequences and "destroy" or shift the layout. Would it even be possible to add additional characters to the font(s)?
I see international characters being mentioned in VT5xx standard. (https://en.wikipedia.org/wiki/VT520)

I totally get it, that something like this is totally off-scope for this project (being a VT102 terminal), I'm rather interested in hearing, what had to be done to achieve such a goal.

Regards, Commander1024

dhansel, 2024-03-03:
VersaTerm allows you to upload up to four user-defined fonts. That should allow you
to define any non-english language character you need. It's not trivial but doable,
I'll be happy to help if you run into problems.

To create a font, create a Windows BMP bitmap file with the following characteristics:
- Windows BMP file format, monochrome, no compression
- characters must be 8 pixels wide and 8-16 pixels high
- bitmap width must be a multiple of 32 pixels
- bitmap height must be a multiple of the character height
- ((bitmap width) * (bitmap height)) must equal (2048 * (character height))

It's easiest to start out with a downloaded bitmap such as this 8x16 VGA font:
http://www.alexandrugroza.ro/microelectronics/essays-research/vga-rom-fonts/_pict/vga-rom-fonts-ag869x16.bmp
I found that on this site:
http://www.alexandrugroza.ro/microelectronics/essays-research/vga-rom-fonts/index.html
but with a bit of searching you can find many more on the web.

You can then modify (or re-order) the characters to in the bitmap your liking.
Or find a font bitmap that has all the characters you need at their expected location.
VersaTerm will the font characters defined in the bitmap to ASCII codes in
order left-to-right, top-to-bottom.

Once you have a font bitmap, connect your PC to VersaTerm either via a usb-to-serial
adapter or by connecting the PC USB port to the Pi Pico's on-board USB micro port.
Note that if you use the Pico's USB micro port then you can't have a USB keyboard
connected at the same time - so you must use a PS/2 keyboard in that case.

Open TeraTerm on your computer and make sure you have a proper connection.
Easy to test by just typing characters in VersaTerm/TeraTerm and checking whether
they show up on the other end.

Once everything is connected properly:
1) In VersaTerm, go to Font Settings->Edit user font 1->Upload font bitmap
2) In TeraTerm, select "File->Transfer->XModem->Send"
3) Select the font bitmap file and click "Ok". That should upload the font.
4) Once the font is uploaded successful you can test it by selecting "View font" in VersaTerm.
5) To make VersaTerm use the font, change the "Font Settings->Normal Font" setting to "User 1"

Writing this out it sounds pretty complicated but it really isn't.
I would suggest just trying to upload the font file I referenced above to test it out.
Once you know how it works you can modify the font to suit your needs.

JacekRuzyczka, 2024-12-22:
OK, it's good to hear that you support extra fonts. **But:** Is communication in UTF-8 also supported? Many recent Unix / Linux systems only support UTF-8 when talking to a terminal, and even the newest VT terminals appeared before the advent of UTF-8.

dhansel, 2024-12-23:
No, UTF-8 is not supported at the moment. When I built this I meant it to be a versatile terminal for
interacting with vintage computers, pre Unicode era.

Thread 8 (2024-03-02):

Modernize the terminal software

Bushwakka, 2024-03-02:
I have worked with ascii terminals for over 35 years running terminals on Zenix then Unix with 8 port serial cards, Running code written in cobol85 to the modern Linux that ran the Cobol with acucobol and away with serial with the faster network terminal connections.

Would like to see this software ported to a raspberry pi b4 with network setups and usb ports being able to accommodate usb printers,

I know this can be done all from Raspbian BUT simple C code with pi os lite on a B4 would be great for people still using cobol text apps n these modern times

SvenMb, 2024-05-29:
This makes no sense (IMHO). This software is specific to a RP2040. On rp4b and other raspberry computer you have lots of other terminal emulators already available, even "better" one, with even more flexibility, optional utf8 support and higher resolution.

But even the basic linux console on rpi can do all VersaTerm is doing and even more.

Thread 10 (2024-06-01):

USB+HDMI only variant? Or PS2+VGA only?

lf94, 2024-06-01:
It'd be amazing to have this shrunk down to just USB and HDMI - these technologies will most likely have many backward compatible devices created for them in the future, just as VGA and PS2 do.

On the other hand, PS2 and VGA are vastly simpler and will probably have the same types of devices for them forever too.

What do you think? I really like that this has a Pi Pico at its core. The other variants have PIC32s....

dhansel, 2024-06-01:
It should actually be pretty easy to remove hardware features of VersaTerm. The [schematic ](https://github.com/dhansel/VersaTerm/blob/main/hardware/PCB/VersaTermSchematic.pdf)is fairly modular, you can just leave out (i.e. not solder onto the PCB) any of the following:
- PS/2 connector and all components connected to it in the schematic
- VGA connector and all resistors connected to it in the schematic
- USB keyboard connector
- HDMI connector and all resistors connected to it in the schematic
- RS232 connector and all components connected to it in the schematic
- TTL serial connector and all components connected to it in the schematic
- Buzzer and all components connected to it in the schematic

The firmware won't care that these are missing. That way you can save some money by not adding features you don't want.

I personally don't have a use for such a reduced version - my goal was to have something versatile that will work with whatever monitor/keyboard combination and serial port I am working with. So I don't think I will design and test build PCB layouts for different combinations of hardware features which I don't need.

But the schematic and current layout (including an EasyEDA backup of the current schematics that can be imported and edited) is [available](https://github.com/dhansel/VersaTerm/tree/main/hardware/PCB) so maybe someone else (you?) wants to take a stab at this. It's a DIY project after all :)

lf94, 2024-06-01:
Fair! I have zero experience with PCB design and just thought maybe it'd be an easy job :) I can take a shot for sure! I guess I will learn a lot.

Closed 2024-06-01.

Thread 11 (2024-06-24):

Feature request and few issues.

Garfius, 2024-06-24:
Hello, this project is awesome, i have just build one of yours, and works pretty nice, but soldering the HDMI was almost impossible.

Just wondering/asking wether this project can run on a '[rp2040-piZero](https://www.waveshare.com/rp2040-pizero.htm)', which already has the HDMI, so no soldering will be needed.

I just bought one rp2040-piZero, so i am ready for testing ;)

By the way... The issues are:

1. I use PS2 keyboard, home and end keys does not send proper escape codes.
2. HDMI output does not detect a [1024*600 display which uses Realtek rtd2660](https://es.aliexpress.com/item/1005002863549499.html).

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

Garfius, 2024-07-17:
Ok, here trying to make it work on a RP2040-PiZero.

Changed speed at 9600 and all the ping, USB keyboard, uart0 removed VGA option.

I included PIN_USBMODE at pins.h because this board does not have this feature, also pin 24 is used for 'HDMI D1+', now works using duPont cable, might change it later.

I've got a red lines problem, compiled using Debug i can only see few maybe 2 lines, on Release i see what following photo shows:

https://github.com/Garfius/VersaTerm-PiZero/blob/main/software/screenshots/rp2040-piZero-alpha.jpg

There is also the binary available:
https://github.com/Garfius/VersaTerm-PiZero/blob/main/rp2040-piZero-alpha.uf2

Any idea?

HELP

Garfius, 2024-07-18:
Nevermind, Sven already did it: https://github.com/SvenMb/VersaTerm

Closed 2024-07-18.

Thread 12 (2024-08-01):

Good news everyone

Garfius, 2024-08-01:
I now give the firmware binary for rp2040-pizero because requieres little-to-none soldering, really neat.

Download link:
https://drive.google.com/file/d/1-nnakJ2nJUDXHnenlX68KcHwPmUIk4nV/view?usp=sharing

Details:
rp2040-pizero is an original WaveShare product which features on-board HDMI connector, plus 2 USB-C, but compatibles can also be found on many other stores.

WARNING
Board shall not be powered after the display, this sets the board in a faled boot state, must use reset button. TECHNICAL DETAIL: the minimal power given tru the HDMI triggers boot, but is not enough to fully boot.

Implementation fork: https://github.com/SvenMb/VersaTerm
Original store product: https://www.waveshare.com/rp2040-pizero.htm
Compiled: Garfius

-------------pins------------
PIN_BUZZER       9
PIN_PS2_DATA     4
PIN_PS2_CLOCK    5
PIN_DEFAULTS    10
PIN_UART_TX   0
PIN_UART_RX   1
PIN_UART_CTS  14
PIN_UART_RTS  15

PICTURES:
Tested on Raspberry Pi ttl serial console at 115200, nano and vim works OK.
https://drive.google.com/file/d/1Bquh8Kzl212IkZvhMha7C1XSPt_0SFJ0/view?usp=sharing
https://drive.google.com/file/d/1GFvVYNnVv1fM0sEC-BaM-IUDM7ijWq8H/view?usp=sharing
https://drive.google.com/file/d/1z9k5rXd9vWykvdpP7N5_rl9ZbmBgtcLK/view?usp=sharing

Suggestion: Use 5 wire JST_connector for serial XH2.54, can be found cheap on aliexpress.

Feel free to use and share all i have included in this non-issue ;-)

Thank you 4 the great work, best vt100 i have found arround.

blit27, 2025-02-14:
Just a note of thanks to both dhansel and Garfius for your contributions.
I wanted a standalone dumb terminal for IOT devices, a homebrew 6502 computer, and a headless linux box. VersaTerm + WaveShare pi pico implementation is the best terminal around for simplicity and function. Turned it on and it just works.
Best regards, Chris

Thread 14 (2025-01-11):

VersaTerm on Pico2 RP2350 SDK2.1

javavi, 2025-01-11:
Can you please update the project to the possibility of assembling for Pico2 (RP2350A) under Pico-SDK 2.1?
With some difficulty (replacing includes and updating the DVI library), I managed to assemble the project under SDK2.1, but only for Pico RP2040. When trying to assemble for Pico2, the main obstacle was the PicoVGA library.

javavi, 2025-01-11:
Here I found an updated PicoVGA library on pico-SDK 2.1 on GitHub
https://github.com/codaris/picovga-cmake

dquadros, 2025-01-11:
I have update an RP2040 project that uses PicoVGA to SDK 2.00. The main problem I found (and it is still present in the fork you linked) is that a new field was introduced in the 'pio_program' structure to support the RP2350. Without this fix the RP2040 PIO is wrongly programmed. I have not tried (yet) to use the SDK 2,1 or adapt the code for the Pico2 (there may be some timing issues due to the faster cores in the RP2350);

You can see my changes at https://github.com/dquadros/RPTerm/commit/62220a25235175abb5872c6580cf0ddf5671453f

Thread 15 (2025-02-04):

USB Keyboard nonfunctional

jdude104, 2025-02-04:
Attempting to reproduce the schematic on a protoboard, and for some reason USB keyboard will not work no matter what I do. I have tried both an OTG adapter directly into the Pico's micro-usb, and a dedicated port wired as such:

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

HDMI works fine, as do the RESET and DEFAULT buttons, I do not have PS/2 or VGA connected. If I connect it to my computer over serial, I can enter keys that way, but obviously this is not ideal. I have attempted building the code myself from source, and that did not solve the issue.

dhansel, 2025-02-04:
What kind of USB keyboard are you connecting? I have found that the version of TinyUSB that VersaTerm currently uses has trouble with some USB hubs - and therefore also with USB keyboards that have integrated hubs. Those issues are resolved in later versions of TinyUSB.

So if you are using some kind of more fancy keyboard (with built-in mouse support or a USB port to plug a mouse into or other extra features) that may be it. If you have one, try a very simple USB keyboard.

Since you have already re-built from source, another thing you can try is to follow my instructions [here](https://github.com/dhansel/VersaTerm/tree/main/software#tinyusb-updates) to update TinyUSB to the latest version. That should fix the USB hub issues.

If that doesn't help then double-check that your TP2/TP3 connections are correct (not accidentally reversed) and that the 5V/GND connections are correct.

Finally, some keyboards can draw a significant amount of power. Make sure that the power supply you are using is up to the task. You could measure the voltage across the 5V/GND on the keyboard while everything is turned on and the keyboard is connected. It shouldn't be too far off from 5V.

dhansel, 2025-02-04:
I just updated the VersaTerm.uf2 file using the latest TinyUSB version. This one works with the USB hubs I have.

jdude104, 2025-02-05:
Voltage is sitting at 5.2V and somewhere about 3-4mA. I verified by splitting a different USB cable that I have the data wires the correct way around and continuity checked to the TP2 and TP3 points. Keyboard is a Dell keyboard that would come with an office computer. New update does not seem to have fixed it, keyboard status lights still not turning on. Would it also failing with a simple OTG adapter plugged directly into the pico indicate anything?

jdude104, 2025-02-05:
Update: If I instead flash the pico with https://github.com/HisashiKato/RunCPM_Pico_DVI_USB_Keyboard, changing the HDMI pins to match the versaterm schematic, the keyboard does function properly, just not when flashed with versaterm

jdude104, 2025-02-17:
Sorry for the delay been a bit busy. The keyboards I've tested but haven't worked include:
Alienware Sk-8165
Dell sk-8115
Logitech G105
Dell KB216d

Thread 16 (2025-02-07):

TTL-input doesn't show anything on screen with my Z80-retrocomputer

Perdita-Olio, 2025-02-07:
Like I wrote in the title, nothing shows on screen when I connect my Z80-retrocomputer to the Versaterm.
Tried different settings, nothing helps.
The Z80-retro-PC works well on the ASCII VT100 video terminal Ver. 1.3 of Geoff Graham.
When I connect the RX and TX of the Versaterm the screen shows what I type in, so far so good.

I made an inverter between the TX from the Z80 and the RX of the Versaterm.
At that moment I get some rubbish on the screen, every time when I press the reset-button of the Z80-board the screen shows almost every time the same string of different figures.
Changing the settings will not help to make it readable. I know the baud-rate, the number of bits etc, the same settings as in the ASCII video terminal, but still no readable text.

I tried the latest firmware, I even took another RPico, looked for short-circuits, all the components on the right position and in the right way, especially the semi-conductors like the diodes.

I'm out of ideas. Can somebody give me a suggestion on what to look at?

KyleCardoza, 2025-04-23:
I had this same issue until just now. I solved it by using a TTL-to-RS232 adapter, and plugging into the DE-9 port instead of TTL serial. Make sure to get one that has RTS/CTS inputs, if you're using ROMWBW.

Cam-analogue, 2025-06-19:
I had the same issue with my SC131 Z80 CP/M machine. The SC131 can only sink about 0.6mA on Tx and can only pull down the RXIA interface to about 2.0V, not low enough to meet the Pico PI threshold for low of 1.8V. The solution is to replace the 1K R29 with 10K. The resistor change drops sink current needed from 2.6mA to 0.26mA, a value the SC131 can easily sink. I also changed R30 to reduce the sink requirement on the CTS.

Perdita-Olio, 2025-07-13:
@ Cam-analogue.

Thanks for your reply. And I can say that was the solution to the problem, changing R29 and R30 into 10kOhm.
Some weeks ago, I had made a converter with a 74HC14, a Schmitt trigger with a wide voltage range and at least that worked, although it was not really stable.
Sometimes characters turned into just anything on the screen.
This week I have holiday and so wanted to try the modification with the resistors this weekend, because it just has to be possible.
And indeed: the best solution without extra parts, ánd stable.
Thank you very much for sharing your solution.

Best regards

dhansel, 2025-07-20:
Thank you for your comments! I have updated the build instructions to mention that a 10k resistor for R29/R30 may be better in some cases.

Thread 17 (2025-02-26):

Building a new uf2 file using VS Code on Windows

mevenson, 2025-02-26:
Is there any way to get the project to play nice with VS Code on Windows? I tried loading the folder into VS Code with no success. I have the pico SDK installed and I have the latest version of the pico support files for VS Code as well as the latest version of VS Code.  I have the GCC 10.3.1 arm-none-eabi compiler selected.

When I run configure in VS Code, I get this:

[main] Configuring project: src
[proc] Executing command: "C:\Program Files\Microsoft Visual Studio\2022\Community\Common7\IDE\CommonExtensions\Microsoft\CMake\CMake\bin\cmake.exe" -DCMAKE_BUILD_TYPE:STRING=Debug -DCMAKE_EXPORT_COMPILE_COMMANDS:BOOL=TRUE "-DCMAKE_C_COMPILER:FILEPATH=C:\Program Files\Raspberry Pi\Pico SDK v1.5.1\gcc-arm-none-eabi\bin\arm-none-eabi-gcc.exe" "-DCMAKE_CXX_COMPILER:FILEPATH=C:\Program Files\Raspberry Pi\Pico SDK v1.5.1\gcc-arm-none-eabi\bin\arm-none-eabi-g++.exe" --no-warn-unused-cli "-SD:/354341-LMDBSERV/ECS/Raspberry Pi pico/projects/VersaTerm-work/software/src" "-Bd:/354341-LMDBSERV/ECS/Raspberry Pi pico/projects/VersaTerm-work/software/src/build" -G "Unix Makefiles"
[cmake] Not searching for unused variables given on the command line.
[cmake] CMake Warning (dev) in CMakeLists.txt:
[cmake]   No project() command is present.  The top-level CMakeLists.txt file must
[cmake]   contain a literal, direct call to the project() command.  Add a line of
[cmake]   code such as
[cmake]
[cmake]     project(ProjectName)
[cmake]
[cmake]   near the top of the file, but after cmake_minimum_required().
[cmake]
[cmake]   CMake is pretending there is a "project(Project)" command on the first
[cmake]   line.
[cmake] This warning is for project developers.  Use -Wno-dev to suppress it.
[cmake]
[cmake] CMake Warning (dev) in CMakeLists.txt:
[cmake]   cmake_minimum_required() should be called prior to this top-level project()
[cmake]   call.  Please see the cmake-commands(7) manual for usage documentation of
[cmake]   both commands.
[cmake] This warning is for project developers.  Use -Wno-dev to suppress it.
[cmake]
[cmake] -- The C compiler identification is GNU 10.3.1
[cmake] -- The CXX compiler identification is GNU 10.3.1
[cmake] -- Detecting C compiler ABI info
[cmake] -- Detecting C compiler ABI info - failed
[cmake] -- Check for working C compiler: C:/Program Files/Raspberry Pi/Pico SDK v1.5.1/gcc-arm-none-eabi/bin/arm-none-eabi-gcc.exe
[cmake] -- Check for working C compiler: C:/Program Files/Raspberry Pi/Pico SDK v1.5.1/gcc-arm-none-eabi/bin/arm-none-eabi-gcc.exe - broken
[cmake] CMake Error at C:/Program Files/Microsoft Visual Studio/2022/Community/Common7/IDE/CommonExtensions/Microsoft/CMake/CMake/share/cmake-3.29/Modules/CMakeTestCCompiler.cmake:67 (message):
[cmake]   The C compiler
[cmake]
[cmake]     "C:/Program Files/Raspberry Pi/Pico SDK v1.5.1/gcc-arm-none-eabi/bin/arm-none-eabi-gcc.exe"
[cmake]
[cmake]   is not able to compile a simple test program.
[cmake]
[cmake]   It fails with the following output:
[cmake]
[cmake]     Change Dir: 'D:/354341-LMDBSERV/ECS/Raspberry Pi pico/projects/VersaTerm-work/software/src/build/CMakeFiles/CMakeScratch/TryCompile-3toubr'
[cmake]
[cmake]     Run Build Command(s): "C:/Program Files/Microsoft Visual Studio/2022/Community/Common7/IDE/CommonExtensions/Microsoft/CMake/CMake/bin/cmake.exe" -E env VERBOSE=1 C:/sberry/c/bin/gmake.exe -f Makefile cmTC_b46e7/fast
[cmake]     C:/sberry/c/bin/gmake.exe  -f CMakeFiles/cmTC_b46e7.dir/build.make CMakeFiles/cmTC_b46e7.dir/build
[cmake]     gmake.exe[1]: Entering directory 'D:/354341-LMDBSERV/ECS/Raspberry Pi pico/projects/VersaTerm-work/software/src/build/CMakeFiles/CMakeScratch/TryCompile-3toubr'
[cmake]     Building C object CMakeFiles/cmTC_b46e7.dir/testCCompiler.c.obj
[cmake]     "C:/Program Files/Raspberry Pi/Pico SDK v1.5.1/gcc-arm-none-eabi/bin/arm-none-eabi-gcc.exe"    -o CMakeFiles/cmTC_b46e7.dir/testCCompiler.c.obj -c "D:/354341-LMDBSERV/ECS/Raspberry Pi pico/projects/VersaTerm-work/software/src/build/CMakeFiles/CMakeScratch/TryCompile-3toubr/testCCompiler.c"
[cmake]     Linking C executable cmTC_b46e7.exe
[cmake]     "C:/Program Files/Microsoft Visual Studio/2022/Community/Common7/IDE/CommonExtensions/Microsoft/CMake/CMake/bin/cmake.exe" -E rm -f CMakeFiles/cmTC_b46e7.dir/objects.a
[cmake]     "C:/Program Files/Raspberry Pi/Pico SDK v1.5.1/gcc-arm-none-eabi/bin/arm-none-eabi-ar.exe" qc CMakeFiles/cmTC_b46e7.dir/objects.a @CMakeFiles/cmTC_b46e7.dir/objects1.rsp
[cmake]     "C:/Program Files/Raspberry Pi/Pico SDK v1.5.1/gcc-arm-none-eabi/bin/arm-none-eabi-gcc.exe" -Wl,--whole-archive CMakeFiles/cmTC_b46e7.dir/objects.a -Wl,--no-whole-archive -o cmTC_b46e7.exe -Wl,--out-implib,libcmTC_b46e7.dll.a -Wl,--major-image-version,0,--minor-image-version,0 @CMakeFiles/cmTC_b46e7.dir/linkLibs.rsp
[cmake]     c:/program files/raspberry pi/pico sdk v1.5.1/gcc-arm-none-eabi/bin/../lib/gcc/arm-none-eabi/10.3.1/../../../../arm-none-eabi/bin/ld.exe: unrecognized option '--major-image-version'
[cmake]     c:/program files/raspberry pi/pico sdk v1.5.1/gcc-arm-none-eabi/bin/../lib/gcc/arm-none-eabi/10.3.1/../../../../arm-none-eabi/bin/ld.exe: use the --help option for usage information
[cmake]     collect2.exe: error: ld returned 1 exit status
[cmake]     gmake.exe[1]: *** [CMakeFiles/cmTC_b46e7.dir/build.make:102: cmTC_b46e7.exe] Error 1
[cmake]     gmake.exe[1]: Leaving directory 'D:/354341-LMDBSERV/ECS/Raspberry Pi pico/projects/VersaTerm-work/software/src/build/CMakeFiles/CMakeScratch/TryCompile-3toubr'
[cmake]     gmake.exe: *** [Makefile:127: cmTC_b46e7/fast] Error 2
[cmake]
[cmake]
[cmake]
[cmake]
[cmake]
[cmake]   CMake will not be able to correctly generate this project.
[cmake] Call Stack (most recent call first):
[cmake]   CMakeLists.txt
[cmake]
[cmake]
[cmake] CMake Warning (dev) in CMakeLists.txt:
[cmake]   No cmake_minimum_required command is present.  A line of code such as
[cmake]
[cmake]     cmake_minimum_required(VERSION 3.29)
[cmake]
[cmake]   should be added at the top of the file.  The version specified may be lower
[cmake]   if you wish to support older CMake versions for this project.  For more
[cmake]   information run "cmake --help-policy CMP0000".
[cmake] This warning is for project developers.  Use -Wno-dev to suppress it.
[cmake]
[cmake] -- Configuring incomplete, errors occurred!
[proc] The command: "C:\Program Files\Microsoft Visual Studio\2022\Community\Common7\IDE\CommonExtensions\Microsoft\CMake\CMake\bin\cmake.exe" -DCMAKE_BUILD_TYPE:STRING=Debug -DCMAKE_EXPORT_COMPILE_COMMANDS:BOOL=TRUE "-DCMAKE_C_COMPILER:FILEPATH=C:\Program Files\Raspberry Pi\Pico SDK v1.5.1\gcc-arm-none-eabi\bin\arm-none-eabi-gcc.exe" "-DCMAKE_CXX_COMPILER:FILEPATH=C:\Program Files\Raspberry Pi\Pico SDK v1.5.1\gcc-arm-none-eabi\bin\arm-none-eabi-g++.exe" --no-warn-unused-cli "-SD:/354341-LMDBSERV/ECS/Raspberry Pi pico/projects/VersaTerm-work/software/src" "-Bd:/354341-LMDBSERV/ECS/Raspberry Pi pico/projects/VersaTerm-work/software/src/build" -G "Unix Makefiles" exited with code: 1

Any help would be greatly appreciated. I want to add telnet support as well as Televideo 950 terminal emulation.

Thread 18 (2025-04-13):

Having issues with v1.2 board

n2hyo, 2025-04-13:
Having issues with v1.2 board, not getting any video but led on the pico flashes with key presses.

On startup without the pico on the pcb i get a long led then a short flash, on the pcb just the
long flash at power up.

Only doing vga.

Any thoughts ?

dhansel, 2025-04-14:
If the LED flashes with key presses then the firmware is generally running. One possibility is that it's running in HDMI output mode but you are using a VGA monitor.

Since you are not using HDMI, did you maybe leave out the resistors related to HDMI? If R23 is missing then the HDMI auto-detection may incorrectly detect an HDMI monitor and switch to HDMI mode. Make sure that R23 is installed on the board.

David

n2hyo, 2025-04-18:
Yes r23 installed, maybe a different resistor value to force it to vga?

Thanks

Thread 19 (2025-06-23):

Mapping the HOME key

rod98, 2025-06-23:
I wanted to utilize my keyboard's HOME (as well as PG UP, PG DN, END) key to work the same way it does on modern computers by creating a custom TERMINFO file;

However, I've discovered that this key is *not* being sent to the host, instead simply returning the cursor to the beginning of the line - as if the terminal received CR, but without alerting the OS in any way, which creates situations when the displayed cursor position and the actual one differ.

Is it intended behavior? Can it be changed with a setting, perhaps?

I realize I could remap HOME to some Function key, and then list *that* one in the TERMINFO entry, but I'd consider the current behavior quite unexpected and counter-intuitive.

dhansel, 2025-07-20:
Thanks again for reporting! The special handling of HOME (and actually also INSERT) was a left-over from testing
that never got removed. I removed it now so HOME/INSERT should behave just like all other special keys
(PGUP, PGDN,END).

Closed 2025-07-20.

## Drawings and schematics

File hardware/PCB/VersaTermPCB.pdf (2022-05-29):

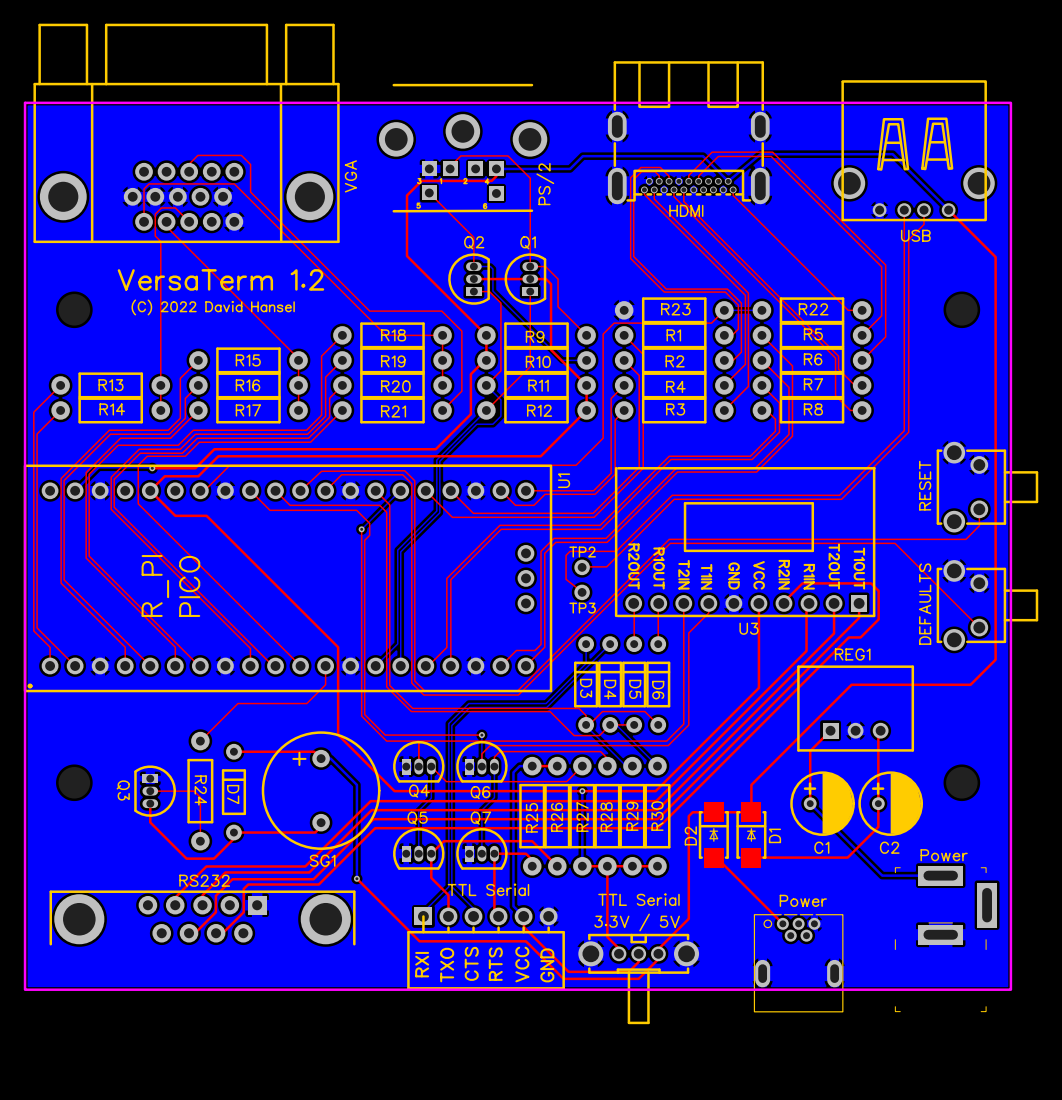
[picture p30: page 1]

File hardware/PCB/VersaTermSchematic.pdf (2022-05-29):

CN4321

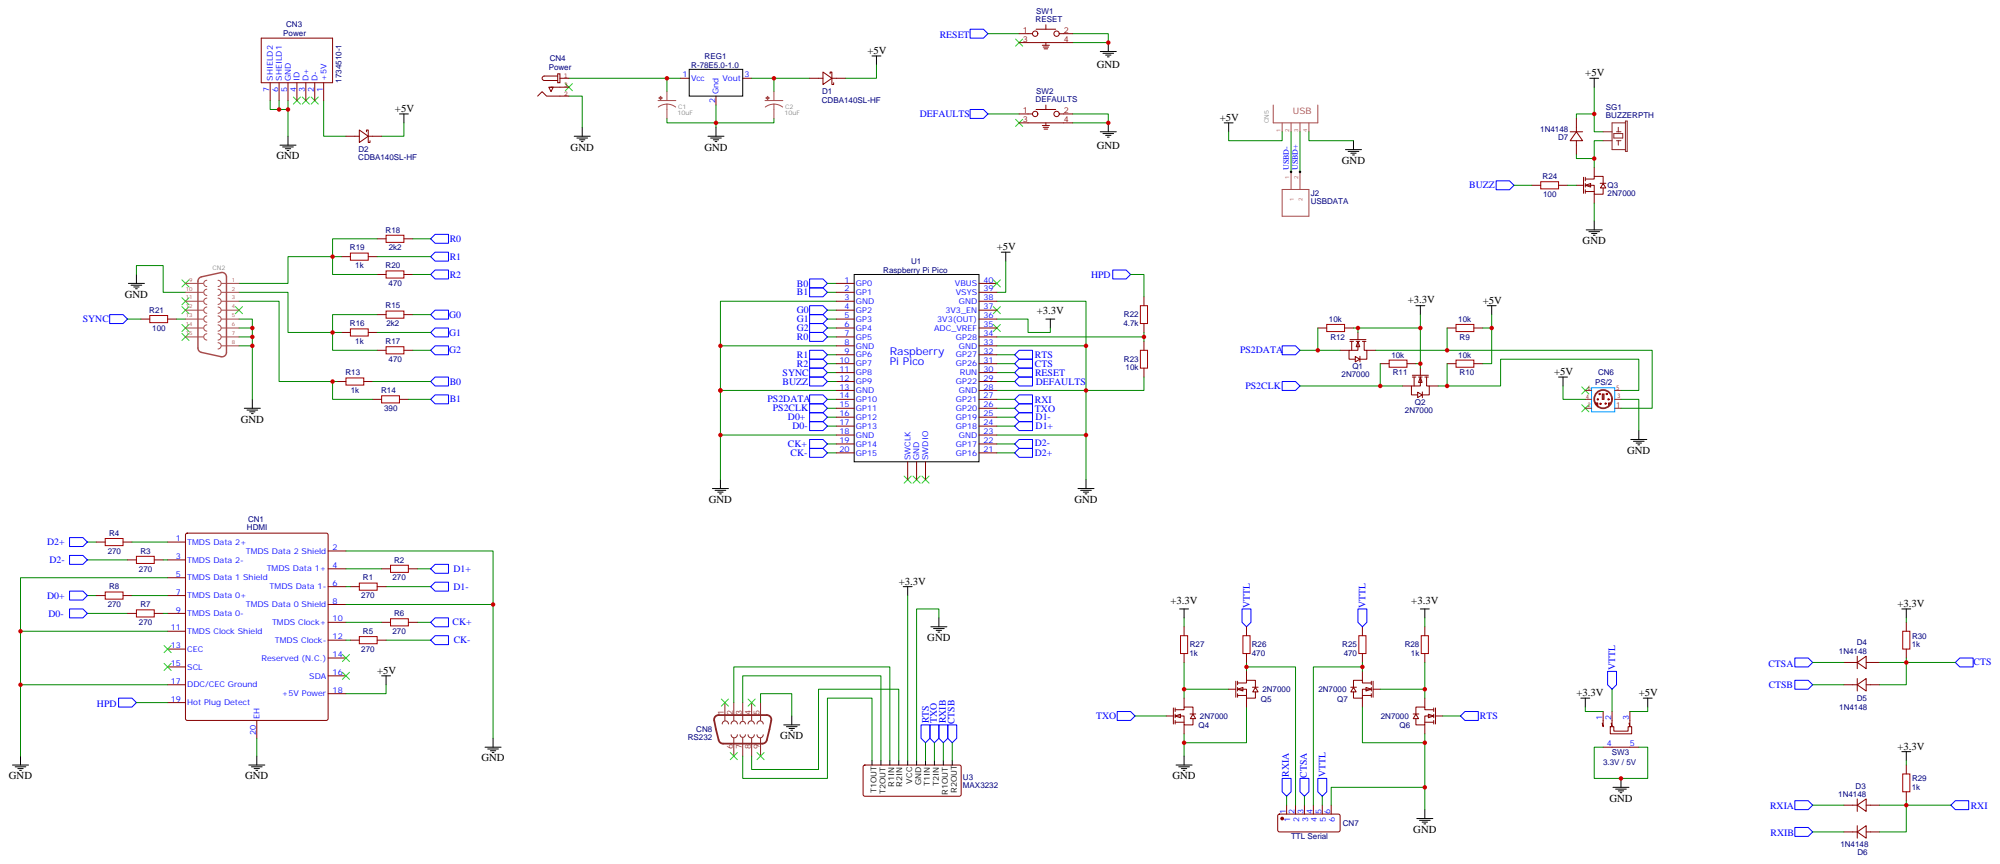
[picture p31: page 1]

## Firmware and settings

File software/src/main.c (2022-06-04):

// -----------------------------------------------------------------------------
// VersaTerm - A versatile serial terminal
// Copyright (C) 2022 David Hansel
//
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
#include <stdio.h>
#include <stdlib.h>
#include <string.h>
#include <ctype.h>
#include "pico/bootrom.h"
#include "tusb.h"
#include "framebuf.h"
#include "serial.h"
#include "keyboard.h"
#include "terminal.h"
#include "config.h"
#include "font.h"
#include "pins.h"
#include "sound.h"


// see comment at start of main()
#define BOOTSEL_TIMEOUT_MS 1500
static absolute_time_t bootsel_timeout = 0;
static const uint32_t bootsel_magic[] = {0xf01681de, 0xbd729b29, 0xd359be7a};
static uint32_t __uninitialized_ram(bootsel_magic_ram)[count_of(bootsel_magic)];
static uint16_t ignore_key = HID_KEY_NONE;


void apply_settings()
{
  font_apply_settings();
  framebuf_apply_settings();
  keyboard_apply_settings();
  terminal_apply_settings();
  serial_apply_settings();
}


void wait(uint32_t milliseconds);

void run_tasks(bool processInput)
{
  // tinyusb tasks
  if( tud_inited() ) tud_task();
  if( tuh_inited() ) tuh_task();
  
  // process serial input
  serial_task(processInput);

  // handle bootsel mechanism timeout
  if( bootsel_timeout>0 && get_absolute_time()>=bootsel_timeout )
    {
      bootsel_timeout = 0;
      for(uint i=0; i<count_of(bootsel_magic); i++) 
        bootsel_magic_ram[i] = 0;
    }
  
  // process keyboard input
  keyboard_task();
  if( processInput && keyboard_num_keypress()>0 )
    {
      uint16_t key = keyboard_read_keypress();
      if( key!=ignore_key )
        {
          ignore_key = HID_KEY_NONE;

          if( key==HID_KEY_F12 )
            {
              if( config_menu() ) apply_settings();
            }
          else if( keyboard_ctrl_pressed(key) && (key&0xFF)==HID_KEY_F12 )
            {
              if( config_load(0xFF) ) apply_settings();
            }
          else if( key==HID_KEY_F11 )
            keyboard_macro_record_startstop();
          else if( keyboard_ctrl_pressed(key) && (key&0xFF)>=HID_KEY_F1 && (key&0xFF)<=HID_KEY_F10 )
            {
              uint8_t vol = config_get_audible_bell_volume();
              if( config_load((key&0xFF)-HID_KEY_F1) )
                {
                  apply_settings();
                  sound_play_tone(880, 50, vol, false);
                }
              else
                {
                  sound_play_tone(880, 50, vol, true); wait(50);
                  sound_play_tone(880, 50, vol, true); wait(50);
                  sound_play_tone(880, 50, vol, false); 
                }
            }
          else
            terminal_process_key(key);
        }
    }
}


void wait(uint32_t milliseconds)
{
  absolute_time_t timeout = make_timeout_time_ms(milliseconds);
  while( get_absolute_time()<timeout ) run_tasks(false);
}


int main()
{
  // The following mechanism is fundamentally the same as the pico_bootsel_via_double_reset
  // library but that library uses a busy wait until the maximum time for the double-tap
  // has expired. Implementing it ourselves here instead allows to use that wait time
  // for initialization.
  uint i;
  for(i=0; i<count_of(bootsel_magic) && bootsel_magic_ram[i]==bootsel_magic[i]; i++);

  if( i<count_of(bootsel_magic) )
    {
      // arm mechanism and set timeout
      for(i=0; i<count_of(bootsel_magic); i++) 
        bootsel_magic_ram[i] = bootsel_magic[i];
      bootsel_timeout = make_timeout_time_ms(BOOTSEL_TIMEOUT_MS);
    }
  else
    {
      // disarm our mechanism so pressing RESET in boot loader starts up normally
      for(i=0; i<count_of(bootsel_magic); i++) 
        bootsel_magic_ram[i] = 0;
      
      // boot into boot-loader using GPIO25 (on-board LED) as activity LED
      reset_usb_boot(1<<25, 0);
    }
  
  config_init();
  stdio_uart_init_full(PIN_UART_ID, 300, PIN_UART_TX, PIN_UART_RX);
  serial_init();

  // initialize USB (needed for keyboard)
  if( config_get_usb_mode()==1 )
    tud_init(TUD_OPT_RHPORT);
  else if( config_get_usb_mode()==2 )
    tuh_init(TUH_OPT_RHPORT);
  else if( config_get_usb_mode()==3 )
    {
      // GPIO24 is high if the Pico's on-board USB port is connected to power (i.e. a host)
      // In that case we want to be a device, otherwise a host
      gpio_init(24);
      gpio_set_dir(24, false); // input
      if( gpio_get(24) )
        tud_init(TUH_OPT_RHPORT);
      else
        tuh_init(TUH_OPT_RHPORT);
    }

  // initialize keyboard
  keyboard_init();

  // allow some time for keyboard(s) to initialize
  wait(tuh_inited() ? 1500 : 250);
  
  // if DEFAULTS button and CTRL key is pressed then force DVI
  if( !gpio_get(PIN_DEFAULTS) )
    framebuf_init((keyboard_get_current_modifiers() & (KEYBOARD_MODIFIER_LEFTCTRL|KEYBOARD_MODIFIER_RIGHTCTRL))!=0);
  else
    {
      // check F1-F10 keys for startup config
      while( keyboard_num_keypress()>0 )
        {
          uint16_t c = keyboard_read_keypress();
          if( (c & 0xFF)>=HID_KEY_F1 && (c & 0xFF)<=HID_KEY_F10 && config_load((c & 0xFF)-HID_KEY_F1) )
            {
              // apply settings (may have changed)
              keyboard_apply_settings();
              serial_apply_settings();
              // ignore further repeats of Fx key 
              ignore_key = c;
              break;
            }
        }

      framebuf_init(false);
    }
  
  terminal_init();
  sound_init();
  config_show_splash();

  while( true ) run_tasks(true);
}

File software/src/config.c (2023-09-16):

// -----------------------------------------------------------------------------
// VersaTerm - A versatile serial terminal
// Copyright (C) 2022 David Hansel
//
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
#include "framebuf.h"
#include "terminal.h"
#include "keyboard.h"
#include "serial.h"
#include "config.h"
#include "font.h"
#include "flash.h"
#include "pins.h"
#include "sound.h"
#include "xmodem.h"
#include <stdarg.h>
#include <ctype.h>
#include <string.h>
#include <stdio.h>
#include <stdlib.h>
#include <math.h>
#include "pico/stdlib.h"
#include "hardware/watchdog.h"
#include "hardware/clocks.h"
#include "tusb.h"

#define CONFIG_MAGIC   0x0F1E2D3C
#define CONFIG_VERSION 0

// defined in main.c
void run_tasks(bool processInput);

#define INFLASHFUN __in_flash(".configfun") 

bool menuActive = false;
uint8_t currentConfig = 0;

static const uint8_t __in_flash(".configmenus") default_colors_ansi_dvi[16] =
  {0b000000, 0b100000, 0b001000, 0b101000, 0b000010, 0b100010, 0b001010, 0b101010, 
   0b010101, 0b110000, 0b001100, 0b111100, 0b000011, 0b110011, 0b001111, 0b111111};

static const uint8_t __in_flash(".configmenus") default_colors_ansi_vga[16] =
  {0b00000000, 0b10000000, 0b00010000, 0b10010000, 0b00000010, 0b10000010, 0b00010010, 0b10010010, 
   0b01001001, 0b11100000, 0b00011100, 0b11111100, 0b00000011, 0b11100011, 0b00011111, 0b11111111};

static const uint8_t __in_flash(".configmenus") default_colors_petscii_dvi[16] =
  {0b000000, 0b111111, 0b100000, 0b001010, 0b100010, 0b001000, 0b000010, 0b111100, 
   0b111000, 0b100100, 0b110000, 0b010101, 0b101010, 0b001100, 0b000011, 0b101010};

static const uint8_t __in_flash(".configmenus") default_colors_petscii_vga[16] =
  {0b00000000, 0b11111111, 0b10000000, 0b00010010, 0b10000010, 0b00010000, 0b00000010, 0b11111100, 
   0b10001000, 0b01000100, 0b11100000, 0b01001001, 0b10010010, 0b00011100, 0b00000011, 0b10110110};


static void INFLASHFUN print(const char *format, ...)
{
  char buffer[101];
  va_list argptr;
  va_start(argptr, format);
  vsnprintf(buffer, 100, format, argptr);
  terminal_receive_string(buffer);
  va_end(argptr);
}


static void INFLASHFUN printLines(uint8_t row, uint8_t col, int numlines, const char lines[][80])
{
  for(int i=0; i<numlines; i++)
    print("\033[%i;%iH%s", row+i, col, lines[i]);
}


static uint8_t waitkey(bool showCursor)
{
  if( showCursor ) print("\033[?25h");
  while( keyboard_num_keypress()==0 ) 
    run_tasks(false);
  if( showCursor ) print("\033[?25l");

  uint16_t key = keyboard_read_keypress();
  if( key==HID_KEY_F11 ) keyboard_macro_record_startstop();

  return keyboard_map_key_ascii(key, NULL);
}


int INFLASHFUN getstring(char *buf, size_t maxlen, bool clear, bool digitsOnly, bool allowCursorKeys)
{
  char bak[101];
  strncpy(bak, buf, 100);
  if( clear ) buf[0] = 0;
  print("%s", buf);
  size_t len = strlen(buf);
  while( 1 )
    {
      uint8_t c = waitkey(false);
      if( c==13 || (allowCursorKeys && (c==KEY_UP || c==KEY_DOWN || c==KEY_LEFT || c==KEY_RIGHT || c==KEY_PUP || c==KEY_PDOWN || c==KEY_HOME || c==KEY_END)) )
        { buf[len]=0; return c; }
      else if( c==27 )
        { strncpy(buf, bak, maxlen); return c; }
      else if( (c==8||c==127) && len>0 )
        { print("\b"); len--; }
      else if( (digitsOnly ? isdigit(c) : isprint(c)) && len<maxlen )
        { print("%c", c); buf[len++]=c; }
    }
}


static void INFLASHFUN printMenuFrame()
{
  print("\016\033[Hlqqqqqqqqqqqqqqqqqqqqqqqqqqqqqqqqqqqqqqqqqqqqqqqqqqqqqqqqqqqqqqqqqqqqqqqqqqqqqqk\n");
  print("x\033[78Cx");
  print("tqqqqqqqqqqqqqqqqqqqqqqqqqqqqqqqqqqqqqqqqqqqqqqqqqqqqqqqqqqqqqqqqqqqqqqqqqqqqqqu\n");
  for(int i=0; i<26; i++) print("x\033[78Cx");
  print("mqqqqqqqqqqqqqqqqqqqqqqqqqqqqqqqqqqqqqqqqqqqqqqqqqqqqqqqqqqqqqqqqqqqqqqqqqqqqqqj\017");
}


static void INFLASHFUN clearToEndOfLine(int row, int col)
{
  print("\033[%i;%iH\033[K\033[%i;80H\016x\017", row, col, row);
}


struct SettingsHeaderStruct
{
  uint32_t magic;
  uint16_t version;
  uint16_t size;
  uint32_t startupConfig; // only used in config 0, specifies which config to load after boot
  char     name[64];
};
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

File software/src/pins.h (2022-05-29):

#ifndef PINS_H
#define PINS_H

// vga output uses gpio pins 0,1,2,3,4,5,6,7,8
// dvi output uses gpio pins 12,13,14,15,16,17,18,19

#define PIN_BUZZER       9
#define PIN_PS2_DATA    10
#define PIN_PS2_CLOCK   11
#define PIN_DEFAULTS    22
#define PIN_LED         25
#define PIN_HDMI_DETECT 28

#define PIN_UART_ID   uart1
#define PIN_UART_TX   20     // uart0: 0, 12, 16, 28  uart1: 4,  8, 20, 24
#define PIN_UART_RX   21     // uart0: 1, 13, 17, 29  uart1: 5,  9, 21, 25
#define PIN_UART_CTS  26     // uart0: 2, 14, 18      uart1: 6, 10, 22, 26
#define PIN_UART_RTS  27     // uart0: 3, 15, 19      uart1: 7, 11  23, 27

#endif

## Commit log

2022-05-29 Added PCB and enclosure
    [VersaTermBOM.xlsx, VersaTermBottom.f3d, VersaTermBottom.stl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]
2022-05-29 Added Gerber file
2022-05-30 Fixed baud rate issue
    [config.c]
2022-06-01 Added picture of unpopulated board
2022-06-03 Fixed USB device config setting
    [config.c]
2022-06-04 A few ESC sequence fixes
2022-08-20 Fixed some keyboard issues
    [keyboard_ps2.c]
2023-04-07 Fixed RS232 level converter component number
    [VersaTermBOM.csv]
2023-10-09 Added enclosure variation provided by Greg@DigicoolThings
    [VersaTermBottom.f3d, VersaTermTop.f3d]
2023-12-28 Removed unnecessary #include directives that caused build fails with recent versions of pico-sdk/tinyusb.
2024-10-14 Updates for 3d files for DigiCoolThings enclosure, fixing issue with text layer
    [VersaTerm.3mf, VersaTermTop.f3d]
2025-02-01 Optimized performace of set/get color code on DVI. Without this we fail the VTTEST "screen features" and "VT102 features" tests at 115200 baud when on DVI.
    [framebuf.c]
2025-02-01 Fixed off-by-one error in "<ESC> [ N d" (set cursor row) command
2025-07-20 Removed special handling of INSERT and HOME keys, instead send corresponding key code to computer (just like PageUp/PageDown etc) This fixes #19

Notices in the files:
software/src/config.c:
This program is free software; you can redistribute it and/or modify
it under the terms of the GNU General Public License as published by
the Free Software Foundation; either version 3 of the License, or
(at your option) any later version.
